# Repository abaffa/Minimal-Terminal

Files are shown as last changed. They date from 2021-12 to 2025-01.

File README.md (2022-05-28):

# Baffa Terminal (minimal-terminal clone) 

This is a Simple Terminal board based on "Minimal-Terminal" project by Carsten Herting (oct/2021 https://github.com/slu4coder/Minimal-Terminal).

Current version supports US-International keyboard mapping, four basic serial speeds (115200, 57600, 38400, 9600 BPS) and [supports some basic CSI/Ansi escapes](supported_escapes.md).
 
The prototype board has been tested with my CP/M machine (see http://baffa-2.baffasoft.com.br) but there is another board compatible with RC2014 pinout. 

### Video
minimal_terminal_video (http://www.youtube.com/watch?v=mmQTUNvmSpk "Baffa-2 Homebrew Microcomputer + Terminal Card")

## Baffa-2 Terminal Board:

[Order Baffa-2 Minimal Terminal PCB from PCBWay](https://www.pcbway.com/project/shareproject/Baffa_2_Minimal_Terminal_f85704c4.html)

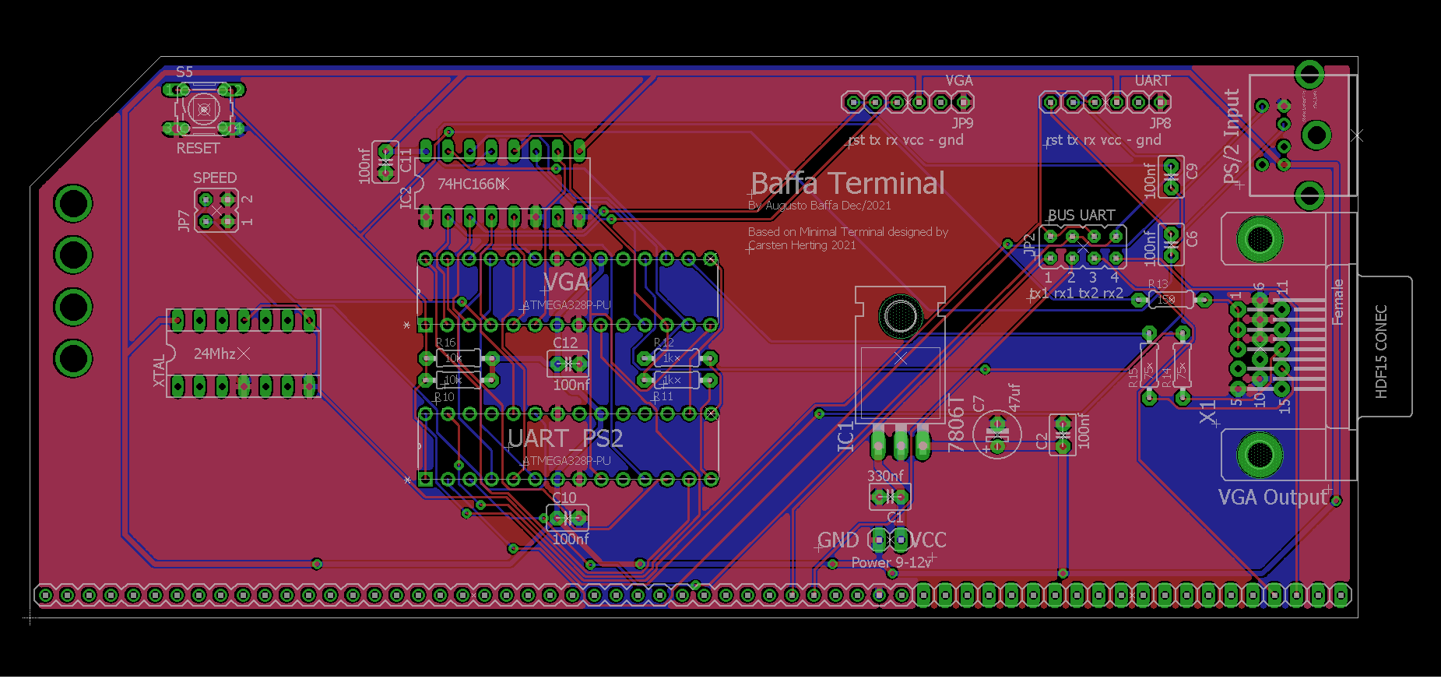
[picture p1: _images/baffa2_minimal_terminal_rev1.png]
minimal_terminalv2


## RC2014 Minimal-Terminal Module

[Order RC2014 Minimal Terminal PCB from PCBWay](https://www.pcbway.com/project/shareproject/RC2014_Minimal_Terminal_41593f8c.html)

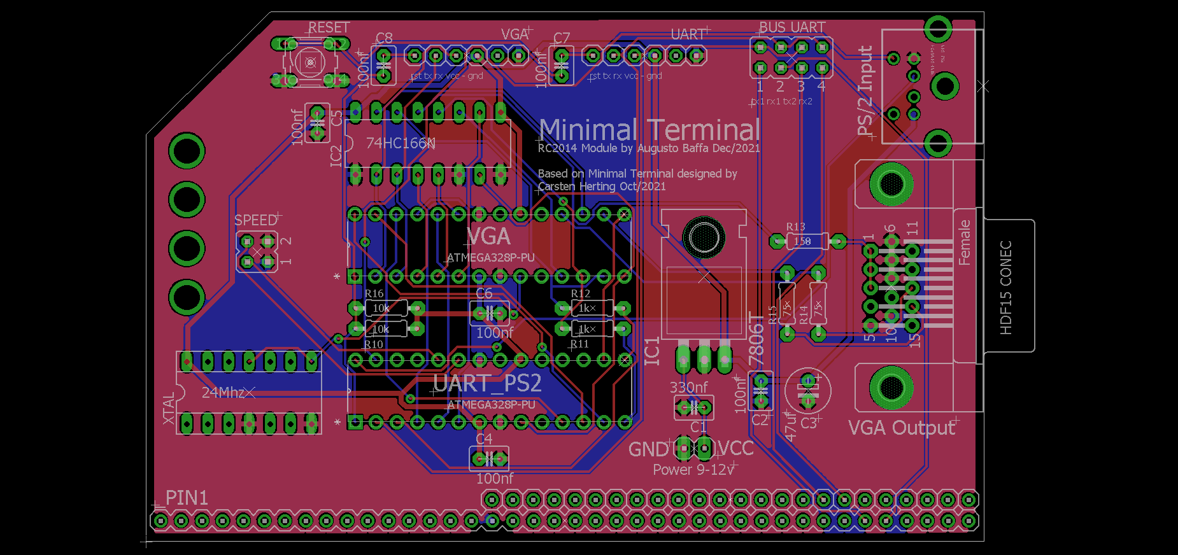
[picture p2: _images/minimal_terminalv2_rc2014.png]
minimal_terminalv2_rc2014


## Bill of Materials

| Qty | Value | Parts | Description |
|:---:|:---:|:-----|:-----|
| 1 |  PINHD-1X20 | JP4 |  PIN HEADER |
| 1 |  PINHD-1X40 | JP3 |  PIN HEADER |
| 6 |  100nf | C2, C6, C9, C10, C11, C12 | CAPACITOR |
| 2 |  10k | R10, R16 | RESISTOR |
| 1 | 150 | R13 | RESISTOR |
| 2 |  1k | R11, R12 | RESISTOR |
| 1 |  24Mhz XTAL |  XTAL |  XTAL SOCKET-14 |
| 1 |  330nf | C1 | CAPACITOR |
| 1 |  47uf | C7 | POLARIZED CAPACITOR |
| 1 |  74HC166N |  IC2 |  8-bit parallel load SHIFT REGISTER |
| 2 | 75 | R14, R15 | RESISTOR, American symbol |
| 1 |  7806T | IC1 |  Positive VOLTAGE REGULATOR |
| 2 |  ATMEGA328P-PU | UART_PS2, VGA |  PDIP-28 Atmel |
| 1 |  BUS UART | JP2 |  JUMPER |
| 1 |  MINI-DIN6PTH |  PS2_DIN |  mini DIN 6 Connector |
| 1 |  Power 9-12v | JP1 |  PIN HEADER |
| 1 |  RESET | S5 | MOM SWITCH |
| 1 |  SPEED | JP7 |  JUMPER |
| 1 | PINHD-1X6 | UART |  PIN HEADER |
| 1 | PINHD-1X6 |  VGA |  PIN HEADER |
| 1 | DSUB | VGA Output | SUB-D |
 
## License

Copyright (c) 2021 Augusto Baffa, Carsten Herting

Permission is hereby granted, free of charge, to any person obtaining a copy
of this software and associated documentation files (the "Software"), to deal
in the Software without restriction, including without limitation the rights
to use, copy, modify, merge, publish, distribute, sublicense, and/or sell
copies of the Software, and to permit persons to whom the Software is
furnished to do so, subject to the following conditions:

The above copyright notice and this permission notice shall be included in all
copies or substantial portions of the Software.

THE SOFTWARE IS PROVIDED "AS IS", WITHOUT WARRANTY OF ANY KIND, EXPRESS OR
IMPLIED, INCLUDING BUT NOT LIMITED TO THE WARRANTIES OF MERCHANTABILITY,
FITNESS FOR A PARTICULAR PURPOSE AND NONINFRINGEMENT. IN NO EVENT SHALL THE
AUTHORS OR COPYRIGHT HOLDERS BE LIABLE FOR ANY CLAIM, DAMAGES OR OTHER
LIABILITY, WHETHER IN AN ACTION OF CONTRACT, TORT OR OTHERWISE, ARISING FROM,
OUT OF OR IN CONNECTION WITH THE SOFTWARE OR THE USE OR OTHER DEALINGS IN THE
SOFTWARE.

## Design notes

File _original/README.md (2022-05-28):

## Original Minimal-Terminal Read.me

Minimal serial UART terminal with VGA and PS2 for up to 230400bps based upon ATmega328P.

This little gadget it ideally suited to be used together with the 'Minimal UART CPU System': https://github.com/slu4coder/Minimal-UART-CPU-System

See the manual section 'Native Tool Chain / Terminal' for more information:
https://docs.google.com/document/d/1c2ZHtLd1BBAwcBAjBZZJmCA3AXpbpv80dlAtsMYpuF4/edit?usp=sharing

---
MIT License

Copyright (c) 2021 Carsten Herting

Permission is hereby granted, free of charge, to any person obtaining a copy
of this software and associated documentation files (the "Software"), to deal
in the Software without restriction, including without limitation the rights
to use, copy, modify, merge, publish, distribute, sublicense, and/or sell
copies of the Software, and to permit persons to whom the Software is
furnished to do so, subject to the following conditions:

The above copyright notice and this permission notice shall be included in all
copies or substantial portions of the Software.

THE SOFTWARE IS PROVIDED "AS IS", WITHOUT WARRANTY OF ANY KIND, EXPRESS OR
IMPLIED, INCLUDING BUT NOT LIMITED TO THE WARRANTIES OF MERCHANTABILITY,
FITNESS FOR A PARTICULAR PURPOSE AND NONINFRINGEMENT. IN NO EVENT SHALL THE
AUTHORS OR COPYRIGHT HOLDERS BE LIABLE FOR ANY CLAIM, DAMAGES OR OTHER
LIABILITY, WHETHER IN AN ACTION OF CONTRACT, TORT OR OTHERWISE, ARISING FROM,
OUT OF OR IN CONNECTION WITH THE SOFTWARE OR THE USE OR OTHER DEALINGS IN THE
SOFTWARE.

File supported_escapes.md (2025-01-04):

# Minimal-Terminal / Supported Escape Sequences

Standard escape codes are prefixed with `Escape`:

- Ctrl-Key: `^[`
- Octal: `\033`
- Unicode: `\u001b`
- Hexadecimal: `\x1B`
- Decimal: `27`

- `CSI` - Control Sequence Introducer: sequence starting with `ESC [` or CSI (`\x9B`)

Followed by the command, somtimes delimited by opening square bracket (`[`), known as a Control Sequence Introducer (CSI), optionally followed by arguments and the command itself.

Arguments are delimeted by semi colon (`;`).

For example:

```sh
\x1b[1;31m  # Set style to bold, red foreground.
```
* Any whitespaces between sequences and arguments should be ignored. They are present for improved readability.

## Supported Cursor Controls

| ESC Code Sequence | Description |
| :--- | :--- |
| `ESC[H` | moves cursor to home position (0, 0) |
| `ESC[{line};{column}H` <br> `ESC[{line};{column}f` | moves cursor to line #, column # |
| `ESC[#A` | moves cursor up # lines |
| `ESC[#B` | moves cursor down # lines |
| `ESC[#C` | moves cursor right # columns |
| `ESC[#d` | moves cursor to an absolute # line |
| `ESC[#D` | moves cursor left # columns |
| `ESC[#E` | moves cursor to beginning of next line, # lines down |
| `ESC[#F` | moves cursor to beginning of previous line, # lines up |
| `ESC[#G` | moves cursor to column # |
| `ESC[#S` | scrolls down # lines |
| `ESC[#T` | scrolls up # lines |

## Supported Erase Functions

| ESC Code Sequence | Description |
| :--- | :--- |
| `ESC[J` | erase in display (same as ESC\[0J) |
| `ESC[0J` | erase from cursor until end of screen |
| `ESC[1J` | erase from cursor to beginning of screen  |
| `ESC[2J` | erase entire screen (set position:0,0) |
| `ESC[K` | erase in line (same as ESC\[0K) |
| `ESC[0K` | erase from cursor to end of line |
| `ESC[1K` | erase start of line to the cursor |
| `ESC[2K` | erase the entire line |

## Support Colors / Graphics Mode

| ESC Code Sequence | Reset Sequence | Description |
| :--- | :--- | :--- |
| `ESC[1;34;{...}m` | | Set graphics modes for cell, separated by semicolon (`;`). |
| `ESC[0m` | | reset all modes (styles and colors) |
| `ESC[7m` | `ESC[27m` | set inverse/reverse mode |

> **Note:** Colors are not supported and are ignored by terminal.

## References

- [Main Reference](https://gist.github.com/fnky/458719343aabd01cfb17a3a4f7296797)
- [Wikipedia: ANSI escape code](https://en.wikipedia.org/wiki/ANSI_escape_code)
- [Build your own Command Line with ANSI escape codes](http://www.lihaoyi.com/post/BuildyourownCommandLinewithANSIescapecodes.html)
- [ascii-table: ANSI Escape sequences](https://web.archive.org/web/20210226122732/http://ascii-table.com/ansi-escape-sequences.php)
- [bluesock: ansi codes](https://bluesock.org/~willkg/dev/ansi.html)
- [bash-hackers: Terminal Codes (ANSI/VT100) introduction](https://web.archive.org/web/20230405000510/https://wiki.bash-hackers.org/scripting/terminalcodes)
- [XTerm Control Sequences](https://invisible-island.net/xterm/ctlseqs/ctlseqs.html)
- [VT100 – Various terminal manuals](https://vt100.net/)
- [xterm.js – Supported Terminal Sequences](https://xtermjs.org/docs/api/vtfeatures/)
- [Microsoft Learn - Console virtual terminal sequences](https://learn.microsoft.com/pt-br/windows/console/console-virtual-terminal-sequences)

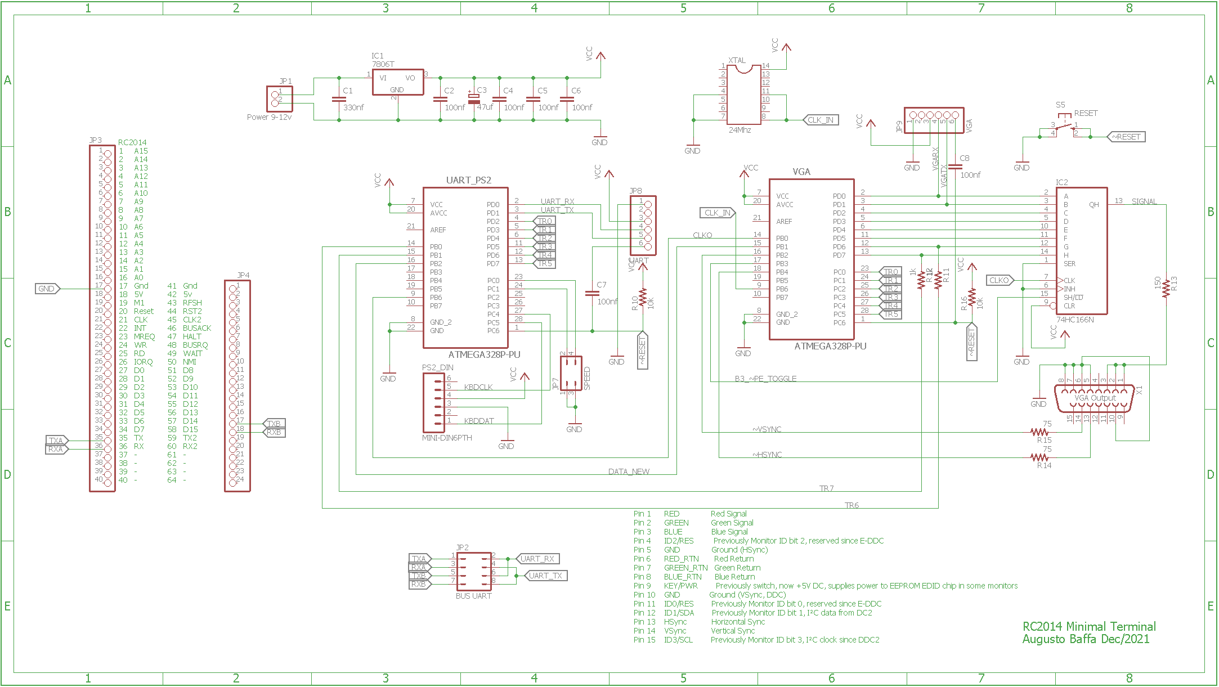
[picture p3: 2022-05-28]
schematics_rc2014_minimal_terminal.png

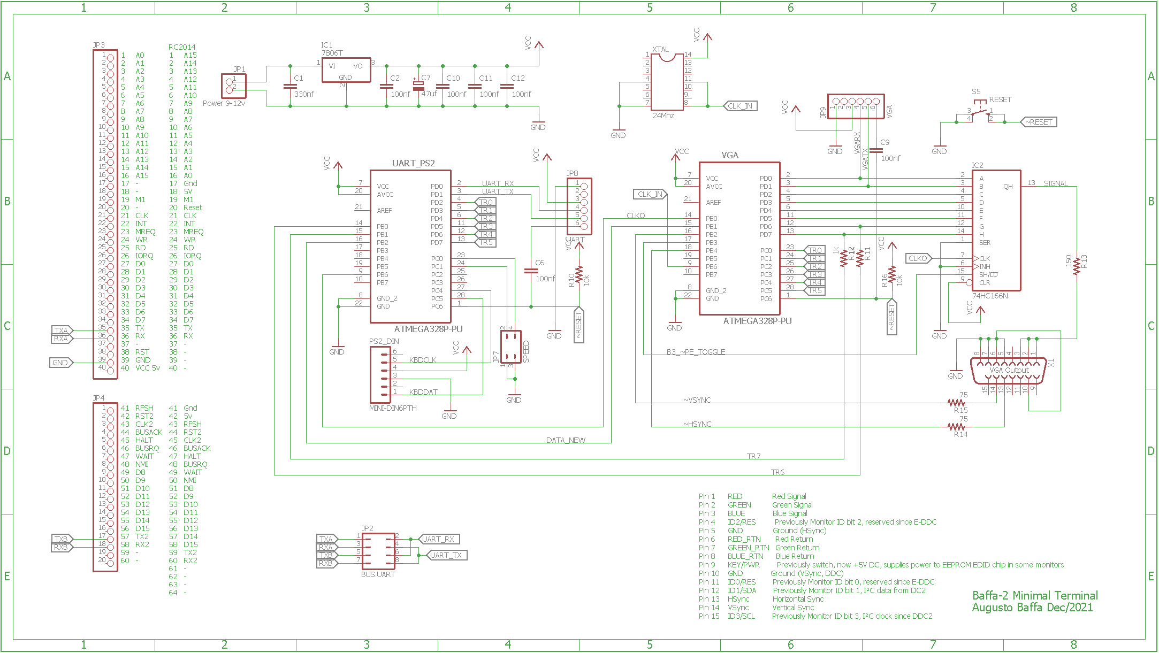
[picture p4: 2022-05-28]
schematics_baffa2_minimal_terminal.png

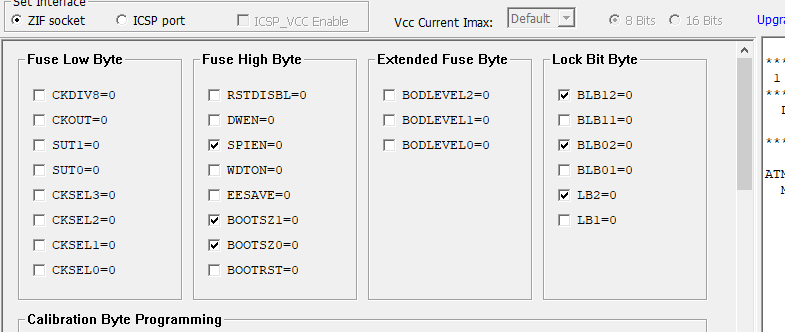
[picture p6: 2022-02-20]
Arduino_UART_Terminal_A_24MHz/fuse.png

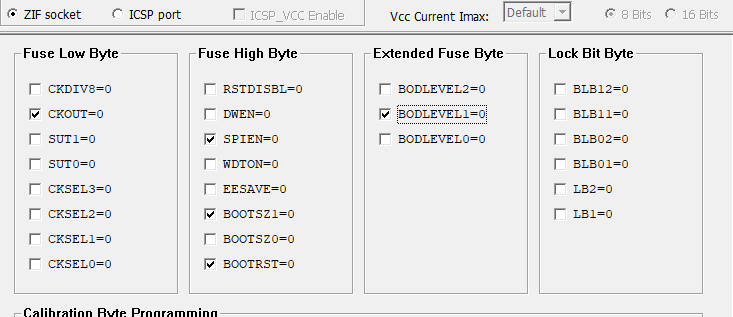
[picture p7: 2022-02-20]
Arduino_UART_Terminal_B_24MHz/fuse.png

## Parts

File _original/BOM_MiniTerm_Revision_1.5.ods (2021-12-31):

Item | Qty | Reference(s) | Value | LibPart | Footprint
1 | 2 | C1, C2 | .1µ | Device:C_Small | Capacitor_THT:C_Disc_D3.8mm_W2.6mm_P2.50mm
2 | 1 | C3 | 47µ | Device:CP | Capacitor_THT:CP_Radial_D6.3mm_P2.50mm
3 | 3 | C4, C9, C10 | .1µ | Device:C | Capacitor_THT:C_Disc_D3.8mm_W2.6mm_P2.50mm
4 | 2 | C5, C7 | 22p | Device:C_Small | Capacitor_THT:C_Disc_D5.0mm_W2.5mm_P2.50mm
5 | 1 | J1 | UART | Connector:Conn_01x06_Female | Connector_PinSocket_2.54mm:PinSocket_1x06_P2.54mm_Vertical
6 | 1 | J2 | PS/2 Keyboard | Connector:Mini-DIN-6 | ArduinoPC:FP_MINI_DIN_6_PS2
7 | 1 | J3 | VGA DB15 HD Connector (Female) | Connector:DB15_Female_HighDensity | ArduinoPC:VGA DSUB15HD_female
8 | 1 | J4 | 5V | Connector:Conn_01x02_Female | Connector_PinSocket_2.54mm:PinSocket_1x02_P2.54mm_Vertical
9 | 1 | J5 | VGA | Connector:Conn_01x06_Female | Connector_PinSocket_2.54mm:PinSocket_1x06_P2.54mm_Vertical
10 | 1 | J6 | SPEED | Connector_Generic:Conn_02x02_Top_Bottom | ArduinoPC:PinHeader_2x02_P2.54mm_Vertical_Jumper
11 | 2 | R1, R2 | 1k | Device:R | Resistor_THT:R_Axial_DIN0207_L6.3mm_D2.5mm_P7.62mm_Horizontal
12 | 2 | R3, R4 | 10k | Device:R | Resistor_THT:R_Axial_DIN0207_L6.3mm_D2.5mm_P7.62mm_Horizontal
13 | 1 | R5 | 150 | Device:R | Resistor_THT:R_Axial_DIN0207_L6.3mm_D2.5mm_P7.62mm_Horizontal
14 | 2 | R6, R7 | 75 | Device:R | Resistor_THT:R_Axial_DIN0207_L6.3mm_D2.5mm_P7.62mm_Horizontal
15 | 1 | SW1 | SW_Push | Switch:SW_Push | Button_Switch_THT:SW_PUSH_6mm
16 | 1 | U1 | 74HC166 | ArduinoPC:74HC166 | Package_DIP:DIP-16_W7.62mm
17 | 1 | U2 | ATmega328P (VGA) | ArduinoPC:ATmega328P-PU | Package_DIP:DIP-28_W7.62mm_Socket
18 | 1 | U3 | ATmega328P (UART & PS/2) | ArduinoPC:ATmega328P-PU | Package_DIP:DIP-28_W7.62mm_Socket
19 | 1 | Y1 | 24MHz | Device:Crystal_Small | Crystal:Crystal_HC18-U_Vertical
20 | 2 |  |  | Jumper

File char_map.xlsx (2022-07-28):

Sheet: Default Font
 | ASCII HEX | 0 | 1 | 2 | 3 | 4 | 5 | 6 | 7 | 8 | 9 | A | B | C | D | E | F | 10 | 11 | 12 | 13 | 14 | 15 | 16 | 17 | 18 | 19 | 1A | 1B | 1C | 1D | 1E | 1F | 20 | 21 | 22 | 23 | 24 | 25 | 26 | 27 | 28 | 29 | 2A | 2B | 2C | 2D | 2E | 2F | 30 | 31 | 32 | 33 | 34 | 35 | 36 | 37 | 38 | 39
Hex | 0x0 | 00 | 00 | 00 | 00 | 00 | 00 | 00 | 00 | 00 | 00 | 00 | 00 | 00 | 00 | 00 | 00 | 00 | 00 | 00 | 00 | 00 | 00 | 00 | 00 | 00 | 00 | 00 | 00 | 00 | 00 | 03 | C0 | 00 | 18 | 66 | 66 | 18 | 62 | 3C | 06 | 0C | 30 | 00 | 00 | 00 | 00 | 00 | 00 | 3C | 18 | 3C | 3C | 06 | 7E | 3C | 7E | 3C | 3C
 | 0x1 | 00 | 00 | 00 | 00 | 00 | 00 | 00 | 00 | 00 | 00 | 00 | 00 | 00 | 00 | 00 | 00 | 00 | 00 | 00 | 00 | 00 | 00 | 00 | 00 | 00 | 00 | 00 | 00 | 00 | 00 | 07 | E0 | 00 | 18 | 66 | 66 | 3E | 66 | 66 | 0C | 18 | 18 | 66 | 18 | 00 | 00 | 00 | 03 | 66 | 18 | 66 | 66 | 0E | 60 | 66 | 66 | 66 | 66
 | 0x2 | 00 | 00 | 00 | 00 | 00 | 00 | 00 | 00 | 00 | 00 | 00 | 00 | 00 | 00 | 00 | 00 | 00 | 00 | 00 | 00 | 00 | 00 | 00 | 00 | 00 | 00 | 00 | 00 | 00 | 00 | 0E | 70 | 00 | 18 | 66 | FF | 60 | 0C | 3C | 18 | 30 | 0C | 3C | 18 | 00 | 00 | 00 | 06 | 6E | 38 | 06 | 06 | 1E | 7C | 60 | 0C | 66 | 66
 | 0x3 | 00 | 00 | 00 | 00 | 00 | 00 | 00 | 00 | 00 | 00 | 00 | 00 | 00 | 00 | 00 | 00 | 00 | 00 | 00 | 00 | 00 | 00 | 00 | 00 | 00 | 00 | 00 | 00 | 00 | 00 | 1C | 38 | 00 | 18 | 00 | 66 | 3C | 18 | 38 | 00 | 30 | 0C | FF | 7E | 00 | 7E | 00 | 0C | 76 | 18 | 0C | 1C | 66 | 06 | 7C | 18 | 3C | 3E
 | 0x4 | 00 | 00 | 00 | 00 | 00 | 00 | 00 | 00 | 00 | 00 | 00 | 00 | 00 | 00 | 00 | 00 | 00 | 00 | 00 | 00 | 00 | 00 | 00 | 00 | 00 | 00 | 00 | 00 | 00 | 00 | 38 | 1C | 00 | 00 | 00 | FF | 06 | 30 | 67 | 00 | 30 | 0C | 3C | 18 | 00 | 00 | 00 | 18 | 66 | 18 | 30 | 06 | 7F | 06 | 66 | 18 | 66 | 06
 | 0x5 | 00 | 00 | 00 | 00 | 00 | 00 | 00 | 00 | 00 | 00 | 00 | 00 | 00 | 00 | 00 | 00 | 00 | 00 | 00 | 00 | 00 | 00 | 00 | 00 | 00 | 00 | 00 | 00 | 00 | 00 | 70 | 0E | 00 | 00 | 00 | 66 | 7C | 66 | 66 | 00 | 18 | 18 | 66 | 18 | 18 | 00 | 18 | 30 | 66 | 18 | 60 | 66 | 06 | 66 | 66 | 18 | 66 | 66
 | 0x6 | 00 | 00 | 00 | 00 | 00 | 00 | 00 | 00 | 00 | 00 | 00 | 00 | 00 | 00 | 00 | 00 | 00 | 00 | 00 | 00 | 00 | 00 | 00 | 00 | 00 | 00 | 00 | 00 | 00 | 00 | E0 | 07 | 00 | 18 | 00 | 66 | 18 | 46 | 3F | 00 | 0C | 30 | 00 | 00 | 18 | 00 | 18 | 60 | 3C | 7E | 7E | 3C | 06 | 3C | 3C | 18 | 3C | 3C
 | 0x7 | 00 | 00 | 00 | 00 | 00 | 00 | 00 | 00 | 00 | 00 | 00 | 00 | 00 | 00 | 00 | 00 | 00 | 00 | 00 | 00 | 00 | 00 | 00 | 00 | 00 | 00 | 00 | 00 | 00 | 00 | C0 | 03 | 00 | 00 | 00 | 00 | 00 | 00 | 00 | 00 | 00 | 00 | 00 | 00 | 30 | 00 | 00 | 00 | 00 | 00 | 00 | 00 | 00 | 00 | 00 | 00 | 00 | 00
Bitmap | 0b0 | ........ | ........ | ........ | ........ | ........ | ........ | ........ | ........ | ........ | ........ | ........ | ........ | ........ | ........ | ........ | ........ | ........ | ........ | ........ | ........ | ........ | ........ | ........ | ........ | ........ | ........ | ........ | ........ | ........ | ........ | ......██ | ██...... | ........ | ...██... | .██..██. | .██..██. | ...██... | .██...█. | ..████.. | .....██. | ....██.. | ..██.... | ........ | ........ | ........ | ........ | ........ | ........ | ..████.. | ...██... | ..████.. | ..████.. | .....██. | .██████. | ..████.. | .██████. | ..████.. | ..████..
 | 0b1 | ........ | ........ | ........ | ........ | ........ | ........ | ........ | ........ | ........ | ........ | ........ | ........ | ........ | ........ | ........ | ........ | ........ | ........ | ........ | ........ | ........ | ........ | ........ | ........ | ........ | ........ | ........ | ........ | ........ | ........ | .....███ | ███..... | ........ | ...██... | .██..██. | .██..██. | ..█████. | .██..██. | .██..██. | ....██.. | ...██... | ...██... | .██..██. | ...██... | ........ | ........ | ........ | ......██ | .██..██. | ...██... | .██..██. | .██..██. | ....███. | .██..... | .██..██. | .██..██. | .██..██. | .██..██.
 | 0b2 | ........ | ........ | ........ | ........ | ........ | ........ | ........ | ........ | ........ | ........ | ........ | ........ | ........ | ........ | ........ | ........ | ........ | ........ | ........ | ........ | ........ | ........ | ........ | ........ | ........ | ........ | ........ | ........ | ........ | ........ | ....███. | .███.... | ........ | ...██... | .██..██. | ████████ | .██..... | ....██.. | ..████.. | ...██... | ..██.... | ....██.. | ..████.. | ...██... | ........ | ........ | ........ | .....██. | .██.███. | ..███... | .....██. | .....██. | ...████. | .█████.. | .██..... | ....██.. | .██..██. | .██..██.
 | 0b3 | ........ | ........ | ........ | ........ | ........ | ........ | ........ | ........ | ........ | ........ | ........ | ........ | ........ | ........ | ........ | ........ | ........ | ........ | ........ | ........ | ........ | ........ | ........ | ........ | ........ | ........ | ........ | ........ | ........ | ........ | ...███.. | ..███... | ........ | ...██... | ........ | .██..██. | ..████.. | ...██... | ..███... | ........ | ..██.... | ....██.. | ████████ | .██████. | ........ | .██████. | ........ | ....██.. | .███.██. | ...██... | ....██.. | ...███.. | .██..██. | .....██. | .█████.. | ...██... | ..████.. | ..█████.
 | 0b4 | ........ | ........ | ........ | ........ | ........ | ........ | ........ | ........ | ........ | ........ | ........ | ........ | ........ | ........ | ........ | ........ | ........ | ........ | ........ | ........ | ........ | ........ | ........ | ........ | ........ | ........ | ........ | ........ | ........ | ........ | ..███... | ...███.. | ........ | ........ | ........ | ████████ | .....██. | ..██.... | .██..███ | ........ | ..██.... | ....██.. | ..████.. | ...██... | ........ | ........ | ........ | ...██... | .██..██. | ...██... | ..██.... | .....██. | .███████ | .....██. | .██..██. | ...██... | .██..██. | .....██.
 | 0b5 | ........ | ........ | ........ | ........ | ........ | ........ | ........ | ........ | ........ | ........ | ........ | ........ | ........ | ........ | ........ | ........ | ........ | ........ | ........ | ........ | ........ | ........ | ........ | ........ | ........ | ........ | ........ | ........ | ........ | ........ | .███.... | ....███. | ........ | ........ | ........ | .██..██. | .█████.. | .██..██. | .██..██. | ........ | ...██... | ...██... | .██..██. | ...██... | ...██... | ........ | ...██... | ..██.... | .██..██. | ...██... | .██..... | .██..██. | .....██. | .██..██. | .██..██. | ...██... | .██..██. | .██..██.
 | 0b6 | ........ | ........ | ........ | ........ | ........ | ........ | ........ | ........ | ........ | ........ | ........ | ........ | ........ | ........ | ........ | ........ | ........ | ........ | ........ | ........ | ........ | ........ | ........ | ........ | ........ | ........ | ........ | ........ | ........ | ........ | ███..... | .....███ | ........ | ...██... | ........ | .██..██. | ...██... | .█...██. | ..██████ | ........ | ....██.. | ..██.... | ........ | ........ | ...██... | ........ | ...██... | .██..... | ..████.. | .██████. | .██████. | ..████.. | .....██. | ..████.. | ..████.. | ...██... | ..████.. | ..████..
 | 0b7 | ........ | ........ | ........ | ........ | ........ | ........ | ........ | ........ | ........ | ........ | ........ | ........ | ........ | ........ | ........ | ........ | ........ | ........ | ........ | ........ | ........ | ........ | ........ | ........ | ........ | ........ | ........ | ........ | ........ | ........ | ██...... | ......██ | ........ | ........ | ........ | ........ | ........ | ........ | ........ | ........ | ........ | ........ | ........ | ........ | ..██.... | ........ | ........ | ........ | ........ | ........ | ........ | ........ | ........ | ........ | ........ | ........ | ........ | ........
 | ASCII DEC | 0 | 1 | 2 | 3 | 4 | 5 | 6 | 7 | 8 | 9 | 10 | 11 | 12 | 13 | 14 | 15 | 16 | 17 | 18 | 19 | 20 | 21 | 22 | 23 | 24 | 25 | 26 | 27 | 28 | 29 | 30 | 31 | 32 | 33 | 34 | 35 | 36 | 37 | 38 | 39 | 40 | 41 | 42 | 43 | 44 | 45 | 46 | 47 | 48 | 49 | 50 | 51 | 52 | 53 | 54 | 55 | 56 | 57
 | Char | #VALUE! | _x0001_ | _x0002_ | _x0003_ | _x0004_ | _x0005_ | _x0006_ | _x0007_ | _x0008_ |  |  | _x000B_ | _x000C_ | _x000D_ | _x000E_ | _x000F_ | _x0010_ | _x0011_ | _x0012_ | _x0013_ | _x0014_ | _x0015_ | _x0016_ | _x0017_ | _x0018_ | _x0019_ | _x001A_ | _x001B_ | _x001C_ | _x001D_ | _x001E_ | _x001F_ |  | ! | " | # | $ | % | & | ' | ( | ) | * | + | , | - | . | / | 0 | 1 | 2 | 3 | 4 | 5 | 6 | 7 | 8 | 9

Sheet: Apple1
 | ASCII HEX | 0 | 1 | 2 | 3 | 4 | 5 | 6 | 7 | 8 | 9 | A | B | C | D | E | F | 10 | 11 | 12 | 13 | 14 | 15 | 16 | 17 | 18 | 19 | 1A | 1B | 1C | 1D | 1E | 1F | 20 | 21 | 22 | 23 | 24 | 25 | 26 | 27 | 28 | 29 | 2A | 2B | 2C | 2D | 2E | 2F | 30 | 31 | 32 | 33 | 34 | 35 | 36 | 37 | 38 | 39
Hex | 0x0 | 00 | 00 | 00 | 00 | 00 | 00 | 00 | 00 | 00 | 00 | 00 | 00 | 00 | 00 | 00 | 00 | 00 | 00 | 00 | 00 | 00 | 00 | 00 | 00 | 00 | 00 | 00 | 00 | 00 | 00 | 00 | 00 | 00 | 00 | 00 | 00 | 00 | 00 | 00 | 00 | 00 | 00 | 00 | 00 | 00 | 00 | 00 | 00 | 00 | 00 | 00 | 00 | 00 | 00 | 00 | 00 | 00 | 00
 | 0x1 | 0e | 04 | 1e | 0e | 1e | 1f | 1f | 0f | 11 | 0e | 01 | 11 | 10 | 11 | 11 | 0e | 1e | 0e | 1e | 0e | 1f | 11 | 11 | 11 | 11 | 11 | 1f | 1f | 00 | 1f | 00 | 00 | 00 | 04 | 0a | 0a | 04 | 18 | 08 | 04 | 04 | 04 | 04 | 00 | 00 | 00 | 00 | 00 | 0e | 04 | 0e | 1f | 02 | 1f | 07 | 1f | 0e | 0e
 | 0x2 | 11 | 0a | 11 | 11 | 11 | 10 | 10 | 10 | 11 | 04 | 01 | 12 | 10 | 1b | 11 | 11 | 11 | 11 | 11 | 11 | 04 | 11 | 11 | 11 | 11 | 11 | 01 | 18 | 10 | 03 | 00 | 00 | 00 | 04 | 0a | 0a | 0f | 19 | 14 | 04 | 08 | 02 | 15 | 04 | 00 | 00 | 00 | 01 | 11 | 0c | 11 | 01 | 06 | 10 | 08 | 01 | 11 | 11
 | 0x3 | 15 | 11 | 11 | 10 | 11 | 10 | 10 | 10 | 11 | 04 | 01 | 14 | 10 | 15 | 19 | 11 | 11 | 11 | 11 | 10 | 04 | 11 | 11 | 11 | 0a | 0a | 02 | 18 | 08 | 03 | 04 | 00 | 00 | 04 | 0a | 1f | 14 | 02 | 14 | 04 | 10 | 01 | 0e | 04 | 00 | 00 | 00 | 02 | 13 | 04 | 01 | 02 | 0a | 1e | 10 | 02 | 11 | 11
 | 0x4 | 17 | 11 | 1e | 10 | 11 | 1e | 1e | 10 | 1f | 04 | 01 | 18 | 10 | 15 | 15 | 11 | 1e | 11 | 1e | 0e | 04 | 11 | 11 | 15 | 04 | 04 | 04 | 18 | 04 | 03 | 0a | 00 | 00 | 04 | 00 | 0a | 0e | 04 | 08 | 00 | 10 | 01 | 04 | 1f | 00 | 1f | 00 | 04 | 15 | 04 | 06 | 06 | 12 | 01 | 1e | 04 | 0e | 0f
 | 0x5 | 16 | 1f | 11 | 10 | 11 | 10 | 10 | 13 | 11 | 04 | 01 | 14 | 10 | 11 | 13 | 11 | 10 | 15 | 14 | 01 | 04 | 11 | 11 | 15 | 0a | 04 | 08 | 18 | 02 | 03 | 11 | 00 | 00 | 04 | 00 | 1f | 05 | 08 | 15 | 00 | 10 | 01 | 0e | 04 | 04 | 00 | 00 | 08 | 19 | 04 | 08 | 01 | 1f | 01 | 11 | 08 | 11 | 01
 | 0x6 | 10 | 11 | 11 | 11 | 11 | 10 | 10 | 11 | 11 | 04 | 11 | 12 | 10 | 11 | 11 | 11 | 10 | 12 | 12 | 11 | 04 | 11 | 0a | 1b | 11 | 04 | 10 | 18 | 01 | 03 | 00 | 00 | 00 | 00 | 00 | 0a | 1e | 13 | 12 | 00 | 08 | 02 | 15 | 04 | 04 | 00 | 00 | 10 | 11 | 04 | 10 | 11 | 02 | 11 | 11 | 08 | 11 | 02
 | 0x7 | 0f | 11 | 1e | 0e | 1e | 1f | 10 | 0f | 11 | 0e | 0e | 11 | 1f | 11 | 11 | 0e | 10 | 0d | 11 | 0e | 04 | 0e | 04 | 11 | 11 | 04 | 1f | 1f | 00 | 1f | 00 | 1f | 00 | 04 | 00 | 0a | 04 | 03 | 0d | 00 | 04 | 04 | 04 | 00 | 08 | 00 | 04 | 00 | 0e | 0e | 1f | 0e | 02 | 0e | 0e | 08 | 0e | 1c
Bitmap | 0b0 | ........ | ........ | ........ | ........ | ........ | ........ | ........ | ........ | ........ | ........ | ........ | ........ | ........ | ........ | ........ | ........ | ........ | ........ | ........ | ........ | ........ | ........ | ........ | ........ | ........ | ........ | ........ | ........ | ........ | ........ | ........ | ........ | ........ | ........ | ........ | ........ | ........ | ........ | ........ | ........ | ........ | ........ | ........ | ........ | ........ | ........ | ........ | ........ | ........ | ........ | ........ | ........ | ........ | ........ | ........ | ........ | ........ | ........
 | 0b1 | ....███. | .....█.. | ...████. | ....███. | ...████. | ...█████ | ...█████ | ....████ | ...█...█ | ....███. | .......█ | ...█...█ | ...█.... | ...█...█ | ...█...█ | ....███. | ...████. | ....███. | ...████. | ....███. | ...█████ | ...█...█ | ...█...█ | ...█...█ | ...█...█ | ...█...█ | ...█████ | ...█████ | ........ | ...█████ | ........ | ........ | ........ | .....█.. | ....█.█. | ....█.█. | .....█.. | ...██... | ....█... | .....█.. | .....█.. | .....█.. | .....█.. | ........ | ........ | ........ | ........ | ........ | ....███. | .....█.. | ....███. | ...█████ | ......█. | ...█████ | .....███ | ...█████ | ....███. | ....███.
 | 0b2 | ...█...█ | ....█.█. | ...█...█ | ...█...█ | ...█...█ | ...█.... | ...█.... | ...█.... | ...█...█ | .....█.. | .......█ | ...█..█. | ...█.... | ...██.██ | ...█...█ | ...█...█ | ...█...█ | ...█...█ | ...█...█ | ...█...█ | .....█.. | ...█...█ | ...█...█ | ...█...█ | ...█...█ | ...█...█ | .......█ | ...██... | ...█.... | ......██ | ........ | ........ | ........ | .....█.. | ....█.█. | ....█.█. | ....████ | ...██..█ | ...█.█.. | .....█.. | ....█... | ......█. | ...█.█.█ | .....█.. | ........ | ........ | ........ | .......█ | ...█...█ | ....██.. | ...█...█ | .......█ | .....██. | ...█.... | ....█... | .......█ | ...█...█ | ...█...█
 | 0b3 | ...█.█.█ | ...█...█ | ...█...█ | ...█.... | ...█...█ | ...█.... | ...█.... | ...█.... | ...█...█ | .....█.. | .......█ | ...█.█.. | ...█.... | ...█.█.█ | ...██..█ | ...█...█ | ...█...█ | ...█...█ | ...█...█ | ...█.... | .....█.. | ...█...█ | ...█...█ | ...█...█ | ....█.█. | ....█.█. | ......█. | ...██... | ....█... | ......██ | .....█.. | ........ | ........ | .....█.. | ....█.█. | ...█████ | ...█.█.. | ......█. | ...█.█.. | .....█.. | ...█.... | .......█ | ....███. | .....█.. | ........ | ........ | ........ | ......█. | ...█..██ | .....█.. | .......█ | ......█. | ....█.█. | ...████. | ...█.... | ......█. | ...█...█ | ...█...█
 | 0b4 | ...█.███ | ...█...█ | ...████. | ...█.... | ...█...█ | ...████. | ...████. | ...█.... | ...█████ | .....█.. | .......█ | ...██... | ...█.... | ...█.█.█ | ...█.█.█ | ...█...█ | ...████. | ...█...█ | ...████. | ....███. | .....█.. | ...█...█ | ...█...█ | ...█.█.█ | .....█.. | .....█.. | .....█.. | ...██... | .....█.. | ......██ | ....█.█. | ........ | ........ | .....█.. | ........ | ....█.█. | ....███. | .....█.. | ....█... | ........ | ...█.... | .......█ | .....█.. | ...█████ | ........ | ...█████ | ........ | .....█.. | ...█.█.█ | .....█.. | .....██. | .....██. | ...█..█. | .......█ | ...████. | .....█.. | ....███. | ....████
 | 0b5 | ...█.██. | ...█████ | ...█...█ | ...█.... | ...█...█ | ...█.... | ...█.... | ...█..██ | ...█...█ | .....█.. | .......█ | ...█.█.. | ...█.... | ...█...█ | ...█..██ | ...█...█ | ...█.... | ...█.█.█ | ...█.█.. | .......█ | .....█.. | ...█...█ | ...█...█ | ...█.█.█ | ....█.█. | .....█.. | ....█... | ...██... | ......█. | ......██ | ...█...█ | ........ | ........ | .....█.. | ........ | ...█████ | .....█.█ | ....█... | ...█.█.█ | ........ | ...█.... | .......█ | ....███. | .....█.. | .....█.. | ........ | ........ | ....█... | ...██..█ | .....█.. | ....█... | .......█ | ...█████ | .......█ | ...█...█ | ....█... | ...█...█ | .......█
 | 0b6 | ...█.... | ...█...█ | ...█...█ | ...█...█ | ...█...█ | ...█.... | ...█.... | ...█...█ | ...█...█ | .....█.. | ...█...█ | ...█..█. | ...█.... | ...█...█ | ...█...█ | ...█...█ | ...█.... | ...█..█. | ...█..█. | ...█...█ | .....█.. | ...█...█ | ....█.█. | ...██.██ | ...█...█ | .....█.. | ...█.... | ...██... | .......█ | ......██ | ........ | ........ | ........ | ........ | ........ | ....█.█. | ...████. | ...█..██ | ...█..█. | ........ | ....█... | ......█. | ...█.█.█ | .....█.. | .....█.. | ........ | ........ | ...█.... | ...█...█ | .....█.. | ...█.... | ...█...█ | ......█. | ...█...█ | ...█...█ | ....█... | ...█...█ | ......█.
 | 0b7 | ....████ | ...█...█ | ...████. | ....███. | ...████. | ...█████ | ...█.... | ....████ | ...█...█ | ....███. | ....███. | ...█...█ | ...█████ | ...█...█ | ...█...█ | ....███. | ...█.... | ....██.█ | ...█...█ | ....███. | .....█.. | ....███. | .....█.. | ...█...█ | ...█...█ | .....█.. | ...█████ | ...█████ | ........ | ...█████ | ........ | ...█████ | ........ | .....█.. | ........ | ....█.█. | .....█.. | ......██ | ....██.█ | ........ | .....█.. | .....█.. | .....█.. | ........ | ....█... | ........ | .....█.. | ........ | ....███. | ....███. | ...█████ | ....███. | ......█. | ....███. | ....███. | ....█... | ....███. | ...███..
 | ASCII DEC | 0 | 1 | 2 | 3 | 4 | 5 | 6 | 7 | 8 | 9 | 10 | 11 | 12 | 13 | 14 | 15 | 16 | 17 | 18 | 19 | 20 | 21 | 22 | 23 | 24 | 25 | 26 | 27 | 28 | 29 | 30 | 31 | 32 | 33 | 34 | 35 | 36 | 37 | 38 | 39 | 40 | 41 | 42 | 43 | 44 | 45 | 46 | 47 | 48 | 49 | 50 | 51 | 52 | 53 | 54 | 55 | 56 | 57
 | Char | #VALUE! | _x0001_ | _x0002_ | _x0003_ | _x0004_ | _x0005_ | _x0006_ | _x0007_ | _x0008_ |  |  | _x000B_ | _x000C_ | _x000D_ | _x000E_ | _x000F_ | _x0010_ | _x0011_ | _x0012_ | _x0013_ | _x0014_ | _x0015_ | _x0016_ | _x0017_ | _x0018_ | _x0019_ | _x001A_ | _x001B_ | _x001C_ | _x001D_ | _x001E_ | _x001F_ |  | ! | " | # | $ | % | & | ' | ( | ) | * | + | , | - | . | / | 0 | 1 | 2 | 3 | 4 | 5 | 6 | 7 | 8 | 9

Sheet: Apple2ExatoPro
 | ASCII HEX | 0 | 1 | 2 | 3 | 4 | 5 | 6 | 7 | 8 | 9 | A | B | C | D | E | F | 10 | 11 | 12 | 13 | 14 | 15 | 16 | 17 | 18 | 19 | 1A | 1B | 1C | 1D | 1E | 1F | 20 | 21 | 22 | 23 | 24 | 25 | 26 | 27 | 28 | 29 | 2A | 2B | 2C | 2D | 2E | 2F | 30 | 31 | 32 | 33 | 34 | 35 | 36 | 37 | 38 | 39
Hex | 0x0 | 1c | 08 | 3c | 1c | 3c | 3e | 3e | 1e | 22 | 1c | 02 | 22 | 20 | 22 | 22 | 1c | 3c | 1c | 3c | 1c | 3e | 22 | 22 | 22 | 22 | 22 | 3e | 3e | 00 | 3e | 00 | 00 | 00 | 08 | 14 | 14 | 08 | 30 | 10 | 08 | 08 | 08 | 08 | 00 | 00 | 00 | 00 | 00 | 1c | 08 | 1c | 3e | 04 | 3e | 0e | 3e | 1c | 1c
 | 0x1 | 22 | 14 | 22 | 22 | 22 | 20 | 20 | 20 | 22 | 08 | 02 | 24 | 20 | 36 | 22 | 22 | 22 | 22 | 22 | 22 | 08 | 22 | 22 | 22 | 22 | 22 | 02 | 30 | 20 | 06 | 00 | 00 | 00 | 08 | 14 | 14 | 1e | 32 | 28 | 08 | 10 | 04 | 2a | 08 | 00 | 00 | 00 | 02 | 22 | 18 | 22 | 02 | 0c | 20 | 10 | 02 | 22 | 22
 | 0x2 | 2a | 22 | 22 | 20 | 22 | 20 | 20 | 20 | 22 | 08 | 02 | 28 | 20 | 2a | 32 | 22 | 22 | 22 | 22 | 20 | 08 | 22 | 22 | 22 | 14 | 14 | 04 | 30 | 10 | 06 | 08 | 00 | 00 | 08 | 14 | 3e | 28 | 04 | 28 | 10 | 20 | 02 | 1c | 08 | 00 | 00 | 00 | 04 | 26 | 08 | 02 | 04 | 14 | 3c | 20 | 04 | 22 | 22
 | 0x3 | 2e | 22 | 3c | 20 | 22 | 3c | 3c | 20 | 3e | 08 | 02 | 30 | 20 | 2a | 2a | 22 | 3c | 22 | 3c | 1c | 08 | 22 | 22 | 2a | 08 | 08 | 08 | 30 | 08 | 06 | 14 | 00 | 00 | 08 | 00 | 14 | 1c | 08 | 10 | 00 | 20 | 02 | 08 | 3e | 00 | 3e | 00 | 08 | 2a | 08 | 0c | 0c | 24 | 02 | 3c | 08 | 1c | 1e
 | 0x4 | 2c | 3e | 22 | 20 | 22 | 20 | 20 | 26 | 22 | 08 | 02 | 28 | 20 | 22 | 26 | 22 | 20 | 2a | 28 | 02 | 08 | 22 | 22 | 2a | 14 | 08 | 10 | 30 | 04 | 06 | 22 | 00 | 00 | 08 | 00 | 3e | 0a | 10 | 2a | 00 | 20 | 02 | 1c | 08 | 08 | 00 | 00 | 10 | 32 | 08 | 10 | 02 | 3e | 02 | 22 | 10 | 22 | 02
 | 0x5 | 20 | 22 | 22 | 22 | 22 | 20 | 20 | 22 | 22 | 08 | 22 | 24 | 20 | 22 | 22 | 22 | 20 | 24 | 24 | 22 | 08 | 22 | 14 | 36 | 22 | 08 | 20 | 30 | 02 | 06 | 00 | 00 | 00 | 00 | 00 | 14 | 3c | 26 | 24 | 00 | 10 | 04 | 2a | 08 | 08 | 00 | 00 | 20 | 22 | 08 | 20 | 22 | 04 | 22 | 22 | 10 | 22 | 04
 | 0x6 | 1e | 22 | 3c | 1c | 3c | 3e | 20 | 1e | 22 | 1c | 1c | 22 | 3e | 22 | 22 | 1c | 20 | 1a | 22 | 1c | 08 | 1c | 08 | 22 | 22 | 08 | 3e | 3e | 00 | 3e | 00 | 00 | 00 | 08 | 00 | 14 | 08 | 06 | 1a | 00 | 08 | 08 | 08 | 00 | 10 | 00 | 08 | 00 | 1c | 1c | 3e | 1c | 04 | 1c | 1c | 10 | 1c | 38
 | 0x7 | 00 | 00 | 00 | 00 | 00 | 00 | 00 | 00 | 00 | 00 | 00 | 00 | 00 | 00 | 00 | 00 | 00 | 00 | 00 | 00 | 00 | 00 | 00 | 00 | 00 | 00 | 00 | 00 | 00 | 00 | 00 | 3f | 00 | 00 | 00 | 00 | 00 | 00 | 00 | 00 | 00 | 00 | 00 | 00 | 00 | 00 | 00 | 00 | 00 | 00 | 00 | 00 | 00 | 00 | 00 | 00 | 00 | 00
Bitmap | 0b0 | ...███.. | ....█... | ..████.. | ...███.. | ..████.. | ..█████. | ..█████. | ...████. | ..█...█. | ...███.. | ......█. | ..█...█. | ..█..... | ..█...█. | ..█...█. | ...███.. | ..████.. | ...███.. | ..████.. | ...███.. | ..█████. | ..█...█. | ..█...█. | ..█...█. | ..█...█. | ..█...█. | ..█████. | ..█████. | ........ | ..█████. | ........ | ........ | ........ | ....█... | ...█.█.. | ...█.█.. | ....█... | ..██.... | ...█.... | ....█... | ....█... | ....█... | ....█... | ........ | ........ | ........ | ........ | ........ | ...███.. | ....█... | ...███.. | ..█████. | .....█.. | ..█████. | ....███. | ..█████. | ...███.. | ...███..
 | 0b1 | ..█...█. | ...█.█.. | ..█...█. | ..█...█. | ..█...█. | ..█..... | ..█..... | ..█..... | ..█...█. | ....█... | ......█. | ..█..█.. | ..█..... | ..██.██. | ..█...█. | ..█...█. | ..█...█. | ..█...█. | ..█...█. | ..█...█. | ....█... | ..█...█. | ..█...█. | ..█...█. | ..█...█. | ..█...█. | ......█. | ..██.... | ..█..... | .....██. | ........ | ........ | ........ | ....█... | ...█.█.. | ...█.█.. | ...████. | ..██..█. | ..█.█... | ....█... | ...█.... | .....█.. | ..█.█.█. | ....█... | ........ | ........ | ........ | ......█. | ..█...█. | ...██... | ..█...█. | ......█. | ....██.. | ..█..... | ...█.... | ......█. | ..█...█. | ..█...█.
 | 0b2 | ..█.█.█. | ..█...█. | ..█...█. | ..█..... | ..█...█. | ..█..... | ..█..... | ..█..... | ..█...█. | ....█... | ......█. | ..█.█... | ..█..... | ..█.█.█. | ..██..█. | ..█...█. | ..█...█. | ..█...█. | ..█...█. | ..█..... | ....█... | ..█...█. | ..█...█. | ..█...█. | ...█.█.. | ...█.█.. | .....█.. | ..██.... | ...█.... | .....██. | ....█... | ........ | ........ | ....█... | ...█.█.. | ..█████. | ..█.█... | .....█.. | ..█.█... | ...█.... | ..█..... | ......█. | ...███.. | ....█... | ........ | ........ | ........ | .....█.. | ..█..██. | ....█... | ......█. | .....█.. | ...█.█.. | ..████.. | ..█..... | .....█.. | ..█...█. | ..█...█.
 | 0b3 | ..█.███. | ..█...█. | ..████.. | ..█..... | ..█...█. | ..████.. | ..████.. | ..█..... | ..█████. | ....█... | ......█. | ..██.... | ..█..... | ..█.█.█. | ..█.█.█. | ..█...█. | ..████.. | ..█...█. | ..████.. | ...███.. | ....█... | ..█...█. | ..█...█. | ..█.█.█. | ....█... | ....█... | ....█... | ..██.... | ....█... | .....██. | ...█.█.. | ........ | ........ | ....█... | ........ | ...█.█.. | ...███.. | ....█... | ...█.... | ........ | ..█..... | ......█. | ....█... | ..█████. | ........ | ..█████. | ........ | ....█... | ..█.█.█. | ....█... | ....██.. | ....██.. | ..█..█.. | ......█. | ..████.. | ....█... | ...███.. | ...████.
 | 0b4 | ..█.██.. | ..█████. | ..█...█. | ..█..... | ..█...█. | ..█..... | ..█..... | ..█..██. | ..█...█. | ....█... | ......█. | ..█.█... | ..█..... | ..█...█. | ..█..██. | ..█...█. | ..█..... | ..█.█.█. | ..█.█... | ......█. | ....█... | ..█...█. | ..█...█. | ..█.█.█. | ...█.█.. | ....█... | ...█.... | ..██.... | .....█.. | .....██. | ..█...█. | ........ | ........ | ....█... | ........ | ..█████. | ....█.█. | ...█.... | ..█.█.█. | ........ | ..█..... | ......█. | ...███.. | ....█... | ....█... | ........ | ........ | ...█.... | ..██..█. | ....█... | ...█.... | ......█. | ..█████. | ......█. | ..█...█. | ...█.... | ..█...█. | ......█.
 | 0b5 | ..█..... | ..█...█. | ..█...█. | ..█...█. | ..█...█. | ..█..... | ..█..... | ..█...█. | ..█...█. | ....█... | ..█...█. | ..█..█.. | ..█..... | ..█...█. | ..█...█. | ..█...█. | ..█..... | ..█..█.. | ..█..█.. | ..█...█. | ....█... | ..█...█. | ...█.█.. | ..██.██. | ..█...█. | ....█... | ..█..... | ..██.... | ......█. | .....██. | ........ | ........ | ........ | ........ | ........ | ...█.█.. | ..████.. | ..█..██. | ..█..█.. | ........ | ...█.... | .....█.. | ..█.█.█. | ....█... | ....█... | ........ | ........ | ..█..... | ..█...█. | ....█... | ..█..... | ..█...█. | .....█.. | ..█...█. | ..█...█. | ...█.... | ..█...█. | .....█..
 | 0b6 | ...████. | ..█...█. | ..████.. | ...███.. | ..████.. | ..█████. | ..█..... | ...████. | ..█...█. | ...███.. | ...███.. | ..█...█. | ..█████. | ..█...█. | ..█...█. | ...███.. | ..█..... | ...██.█. | ..█...█. | ...███.. | ....█... | ...███.. | ....█... | ..█...█. | ..█...█. | ....█... | ..█████. | ..█████. | ........ | ..█████. | ........ | ........ | ........ | ....█... | ........ | ...█.█.. | ....█... | .....██. | ...██.█. | ........ | ....█... | ....█... | ....█... | ........ | ...█.... | ........ | ....█... | ........ | ...███.. | ...███.. | ..█████. | ...███.. | .....█.. | ...███.. | ...███.. | ...█.... | ...███.. | ..███...
 | 0b7 | ........ | ........ | ........ | ........ | ........ | ........ | ........ | ........ | ........ | ........ | ........ | ........ | ........ | ........ | ........ | ........ | ........ | ........ | ........ | ........ | ........ | ........ | ........ | ........ | ........ | ........ | ........ | ........ | ........ | ........ | ........ | ..██████ | ........ | ........ | ........ | ........ | ........ | ........ | ........ | ........ | ........ | ........ | ........ | ........ | ........ | ........ | ........ | ........ | ........ | ........ | ........ | ........ | ........ | ........ | ........ | ........ | ........ | ........
 | ASCII DEC | 0 | 1 | 2 | 3 | 4 | 5 | 6 | 7 | 8 | 9 | 10 | 11 | 12 | 13 | 14 | 15 | 16 | 17 | 18 | 19 | 20 | 21 | 22 | 23 | 24 | 25 | 26 | 27 | 28 | 29 | 30 | 31 | 32 | 33 | 34 | 35 | 36 | 37 | 38 | 39 | 40 | 41 | 42 | 43 | 44 | 45 | 46 | 47 | 48 | 49 | 50 | 51 | 52 | 53 | 54 | 55 | 56 | 57
 | Char | #VALUE! | _x0001_ | _x0002_ | _x0003_ | _x0004_ | _x0005_ | _x0006_ | _x0007_ | _x0008_ |  |  | _x000B_ | _x000C_ | _x000D_ | _x000E_ | _x000F_ | _x0010_ | _x0011_ | _x0012_ | _x0013_ | _x0014_ | _x0015_ | _x0016_ | _x0017_ | _x0018_ | _x0019_ | _x001A_ | _x001B_ | _x001C_ | _x001D_ | _x001E_ | _x001F_ |  | ! | " | # | $ | % | & | ' | ( | ) | * | + | , | - | . | / | 0 | 1 | 2 | 3 | 4 | 5 | 6 | 7 | 8 | 9
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

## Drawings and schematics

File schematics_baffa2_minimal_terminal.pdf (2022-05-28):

A

A

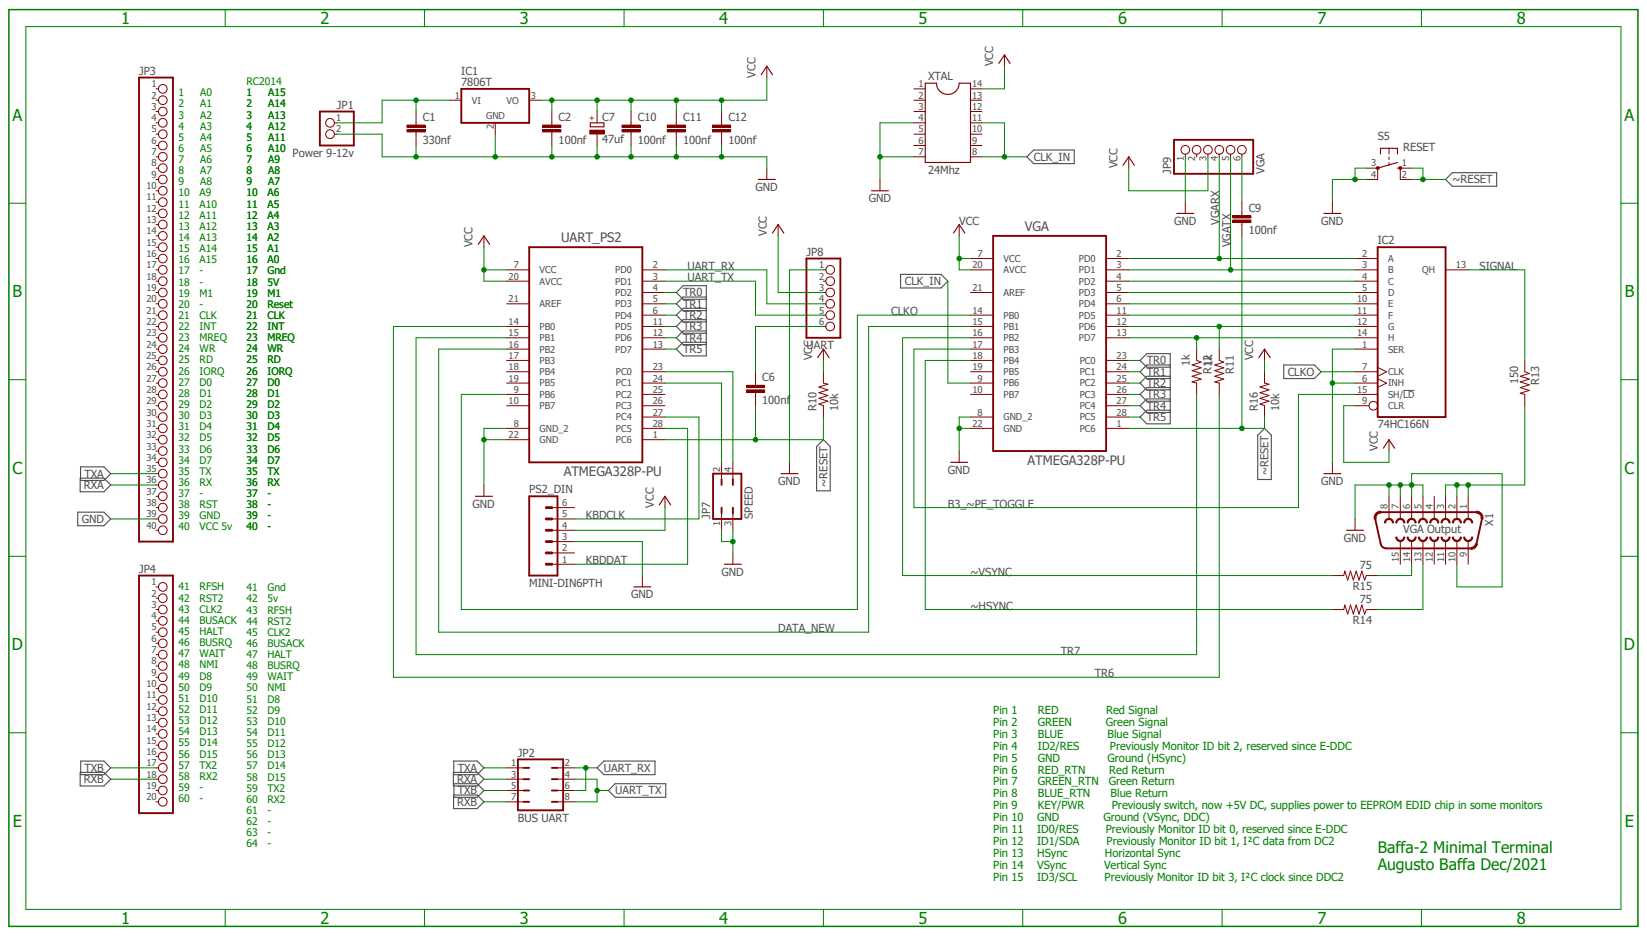
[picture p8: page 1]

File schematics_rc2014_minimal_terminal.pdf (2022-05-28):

A

A

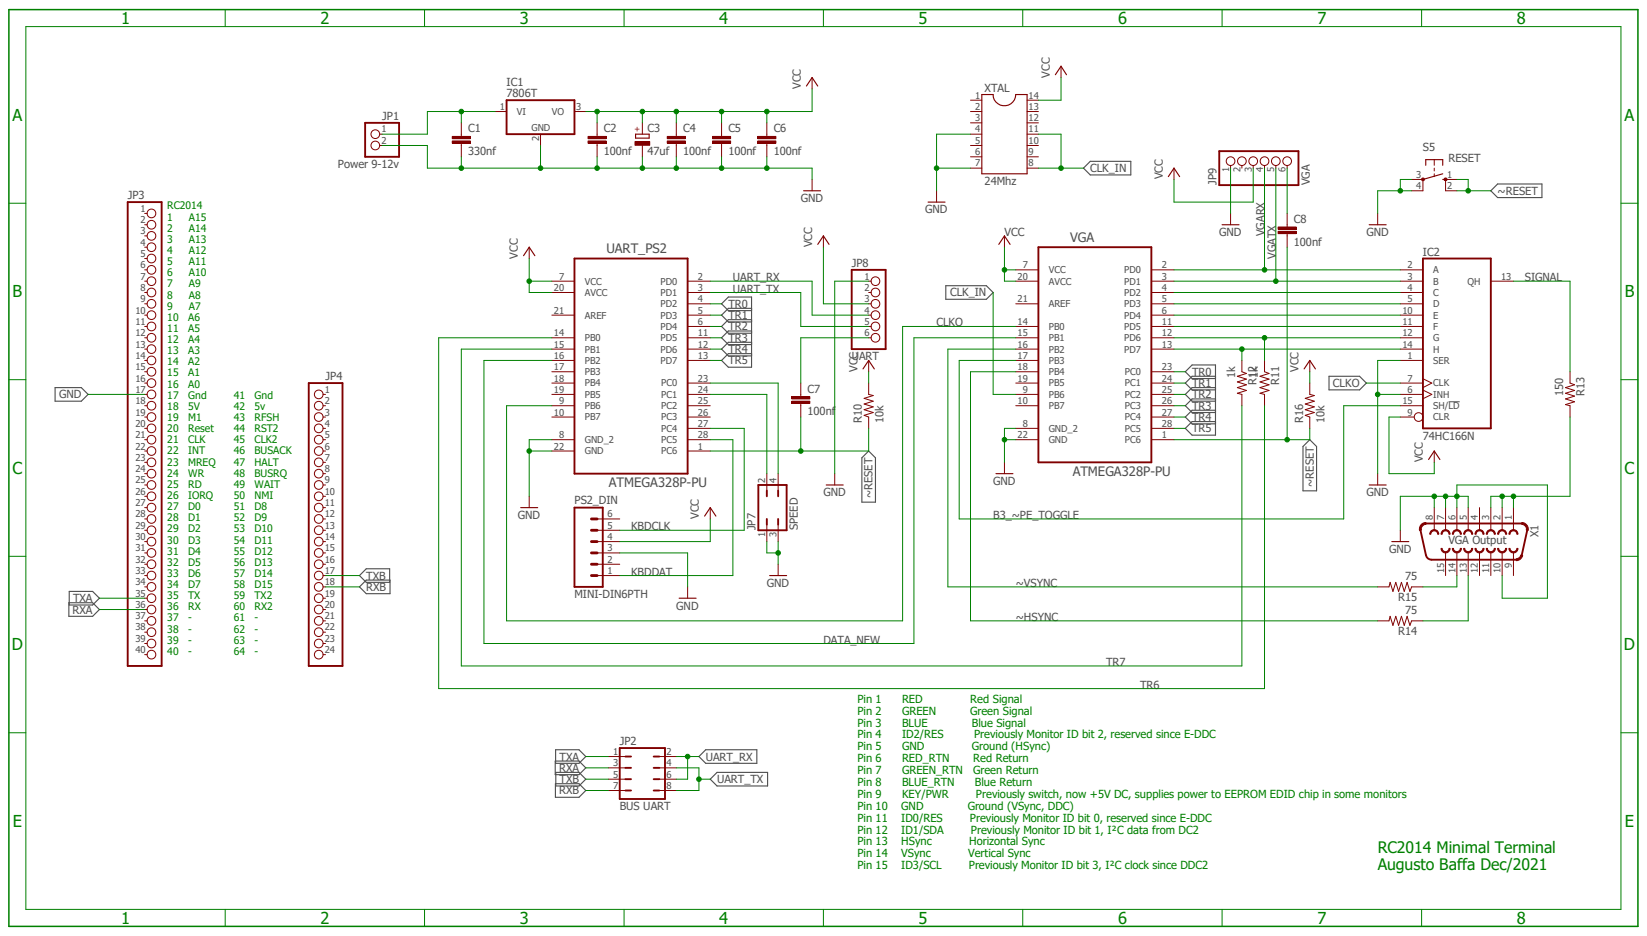
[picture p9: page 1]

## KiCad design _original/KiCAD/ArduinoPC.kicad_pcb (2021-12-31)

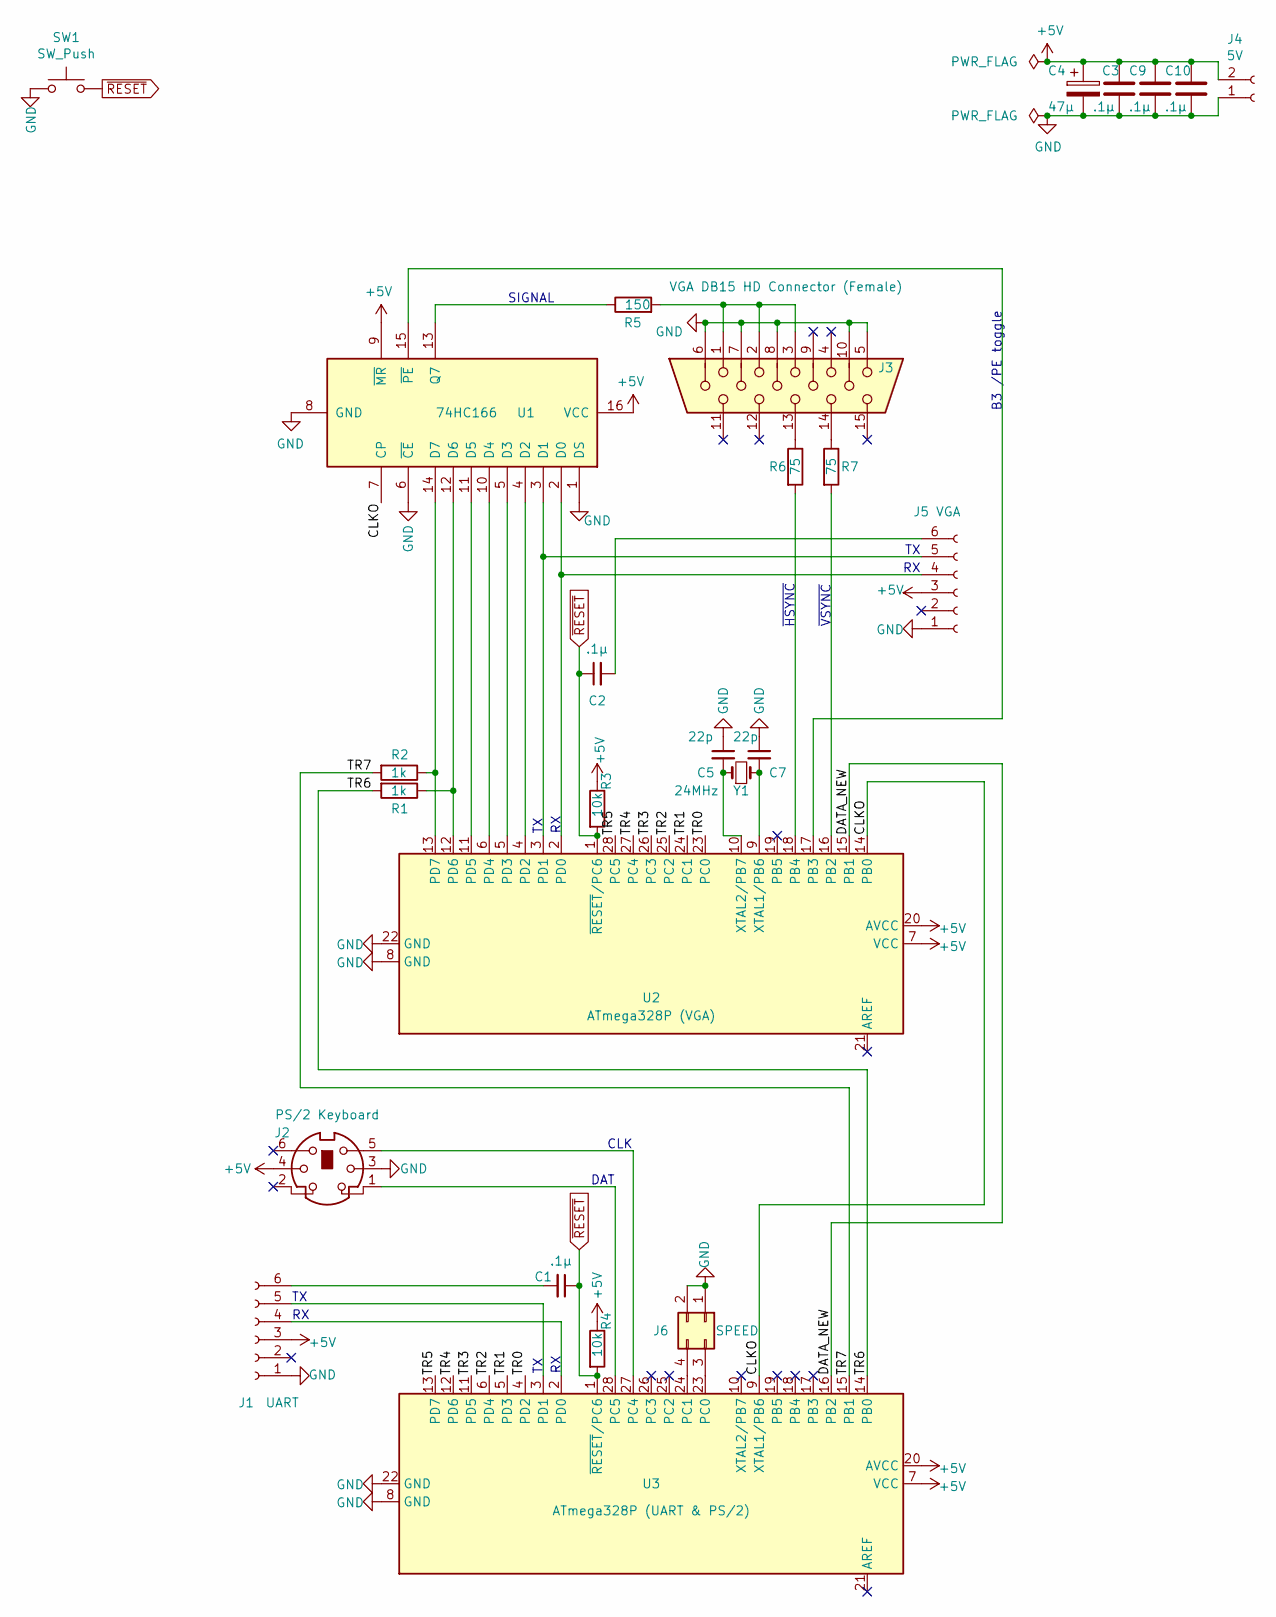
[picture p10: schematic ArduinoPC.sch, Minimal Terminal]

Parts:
C1, C2, C4, C9, C10: .1µ; C_Disc_D3.8mm_W2.6mm_P2.50mm
C3: 47µ; CP_Radial_D6.3mm_P2.50mm
C5, C7: 22p; C_Disc_D5.0mm_W2.5mm_P2.50mm
J1: UART; PinSocket_1x06_P2.54mm_Vertical
J2: PS/2 Keyboard; FP_MINI_DIN_6_PS2
J3: VGA DB15 HD Connector (Female); VGA DSUB15HD_female
J4: 5V; PinSocket_1x02_P2.54mm_Vertical
J5: VGA; PinSocket_1x06_P2.54mm_Vertical
J6: SPEED; PinHeader_2x02_P2.54mm_Vertical_Jumper
R1, R2: 1k; R_Axial_DIN0207_L6.3mm_D2.5mm_P7.62mm_Horizontal
R3, R4: 10k; R_Axial_DIN0207_L6.3mm_D2.5mm_P7.62mm_Horizontal
R5: 150; R_Axial_DIN0207_L6.3mm_D2.5mm_P7.62mm_Horizontal
R6, R7: 75; R_Axial_DIN0207_L6.3mm_D2.5mm_P7.62mm_Horizontal
SW1: SW_Push; SW_PUSH_6mm
U1: 74HC166; DIP-16_W7.62mm
U2: ATmega328P (VGA); DIP-28_W7.62mm_Socket
U3: ATmega328P (UART & PS/2); DIP-28_W7.62mm_Socket
Y1: 24MHz; Crystal_HC18-U_Vertical

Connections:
+5V: C3.1, C4.1, C9.1, C10.1, J1.3, J2.4, J4.2, J5.3, R3.1, R4.1, U1.9 (~MR), U1.16 (VCC), U2.7 (VCC), U2.20 (AVCC), U3.7 (VCC), U3.20 (AVCC)
/CLKO: U1.7 (CP), U2.14 (PB0), U3.9 (XTAL1/PB6)
/DATA_NEW: U2.15 (PB1), U3.16 (PB2)
/TR0: U2.23 (PC0), U3.4 (PD2)
/TR1: U2.24 (PC1), U3.5 (PD3)
/TR2: U2.25 (PC2), U3.6 (PD4)
/TR3: U2.26 (PC3), U3.11 (PD5)
/TR4: U2.27 (PC4), U3.12 (PD6)
/TR5: U2.28 (PC5), U3.13 (PD7)
/TR6: R1.2, U3.14 (PB0)
/TR7: R2.2, U3.15 (PB1)
GND: C3.2, C4.2, C5.1, C7.1, C9.2, C10.2, J1.1, J2.3, J3.5, J3.6, J3.7, J3.8, J3.10, J4.1, J5.1, J6.1, J6.2, SW1.1, U1.1 (DS), U1.6 (~CE), U1.8 (GND), U2.8 (GND), U2.22 (GND), U3.8 (GND), U3.22 (GND)
unnamed: C1.2, J1.6
unnamed: C2.2, J5.6
unnamed: C5.2, U2.10 (XTAL2/PB7), Y1.1
unnamed: C7.2, U2.9 (XTAL1/PB6), Y1.2
unnamed: J1.4, U3.2 (PD0)
unnamed: J1.5, U3.3 (PD1)
unnamed: J2.1, U3.28 (PC5)
unnamed: J2.5, U3.27 (PC4)
unnamed: J3.1, J3.2, J3.3, R5.2
unnamed: J3.13, R6.1
unnamed: J3.14, R7.1
unnamed: J5.4, U1.2 (D0), U2.2 (PD0)
unnamed: J5.5, U1.3 (D1), U2.3 (PD1)
unnamed: J6.3, U3.23 (PC0)
unnamed: J6.4, U3.24 (PC1)
unnamed: R1.1, U1.12 (D6), U2.12 (PD6)
unnamed: R2.1, U1.14 (D7), U2.13 (PD7)
unnamed: R5.1, U1.13 (Q7)
unnamed: R6.2, U2.18 (PB4)
unnamed: R7.2, U2.16 (PB2)
unnamed: U1.4 (D2), U2.4 (PD2)
unnamed: U1.5 (D3), U2.5 (PD3)
unnamed: U1.10 (D4), U2.6 (PD4)
unnamed: U1.11 (D5), U2.11 (PD5)
unnamed: U1.15 (~PE), U2.17 (PB3)
~RESET: C1.1, C2.1, R3.2, R4.2, SW1.2, U2.1 (~RESET~/PC6), U3.1 (~RESET~/PC6)

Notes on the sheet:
SIGNAL
~VSYNC
~HSYNC
B3 /PE toggle
DAT
CLK

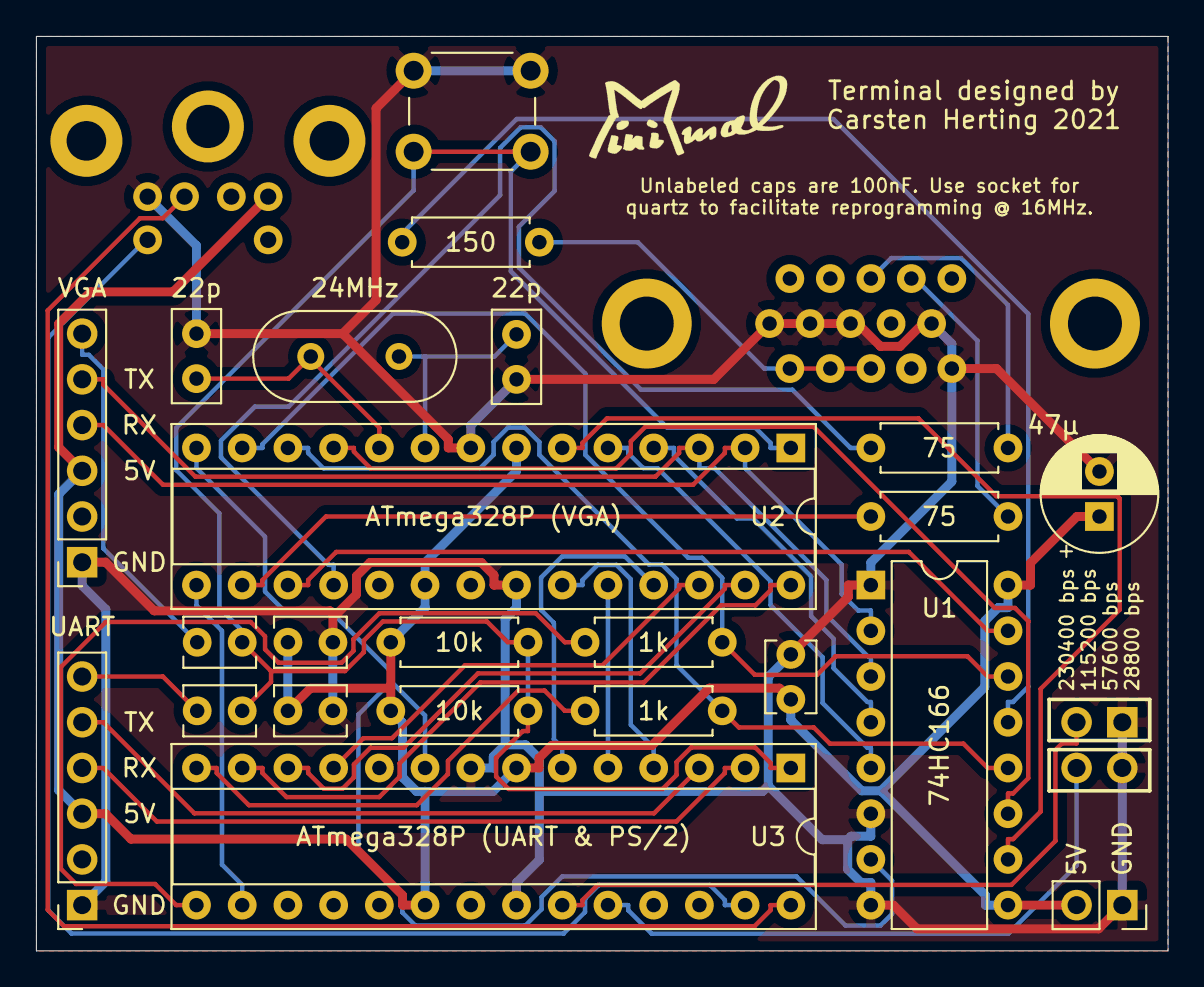
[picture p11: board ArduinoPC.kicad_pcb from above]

Board: 2 copper layers, 62.9 x 50.8 mm, 26 parts (0 on the bottom side), 38 nets.

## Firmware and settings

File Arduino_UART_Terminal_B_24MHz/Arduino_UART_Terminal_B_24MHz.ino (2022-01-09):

// ***************************************************************************
// *****                                                                 *****
// ***** AtMega328P UART ANSI Terminal with 60x25 Character VGA and PS/2 *****
// *****                                                                 *****
// *****        written by Carsten Herting 02.06.2021 Version 2.2        *****
// *****        US-International version by Augusto Baffa Dec/21         ***** 
// *****                                                                 *****
// ***************************************************************************
// Pin C0-5: terminal input bits 0-5
// Pin D0-7: parallel pixel output to 74166, in between: D6-7 terminal input bits 6-7
// Pin B0:   CLKO ATmega328 system clock output
// Pin B1:   DATA_NEW input handshake
// Pin B2:   /VSYNC VGA (timer1, every 1/60s, could also be done)
// Pin B3:   /PE low pulse (by hand inside ISR for 74166 /PE pixel shift register sync parallel load)
// Pin B4:   /HSYNC VGA (by hand inside ISR, every 32µs)
// Pin B5:   DATA_ACK output handshake
// See license at the end of this file.
//
// ** Fixed Escapes to clean line and screen jan, 6 2022 Augusto Baffa
// Fuse: BF | DA | FD | FF

#define WIDTH     60
#define HEIGHT    25

char row = 0, col = 0;            // current cursor position in terminal window
//char saved_row = 0, saved_col = 0;            // current cursor position in terminal window
//bool show_cursor = true;

volatile int vline = 0;           // current vertical position of pixel video output
volatile byte vram[HEIGHT][WIDTH];// array of VideoRAM
volatile char start = 0;          // start line of the VideoRAM (thus avoiding moving data while scrolling)
volatile int frames = 0;          // 1/60s frame counter for cursor blinking
volatile byte regout = 0;         // index of current output position in queue
volatile byte regin = 0;          // index of current input position in queue
volatile byte __attribute__ ((aligned (256))) reg[256];   // ring buffer data of keyboard input register

const volatile byte __attribute__ ((aligned (256))) charset[8][256] PROGMEM =
{
  0x00, 0x00, 0x00, 0x00, 0x00, 0x00, 0x00, 0x00, 0x00, 0x00, 0x00, 0x00, 0x00, 0x00, 0x00, 0x00, 0x00, 0x00, 0x00, 0x00, 0x00, 0x00, 0x00, 0x00, 0x00, 0x00, 0x00, 0x00, 0x00, 0x00, 0x03, 0xC0, 0x00, 0x18, 0x66, 0x66, 0x18, 0x62, 0x3C, 0x06, 0x0C, 0x30, 0x00, 0x00, 0x00, 0x00, 0x00, 0x00, 0x3C, 0x18, 0x3C, 0x3C, 0x06, 0x7E, 0x3C, 0x7E, 0x3C, 0x3C, 0x00, 0x00, 0x0E, 0x00, 0x70, 0x3C, 0x3C, 0x18, 0x7C, 0x3C, 0x78, 0x7E, 0x7E, 0x3C, 0x66, 0x3C, 0x1E, 0x66, 0x60, 0x63, 0x66, 0x3C, 0x7C, 0x3C, 0x7C, 0x3C, 0x7E, 0x66, 0x66, 0x63, 0x66, 0x66, 0x7E, 0x3C, 0x00, 0x3C, 0x00, 0x00, 0x60, 0x00, 0x00, 0x00, 0x00, 0x00, 0x00, 0x00, 0x00, 0x00, 0x00, 0x00, 0x00, 0x00, 0x00, 0x00, 0x00, 0x00, 0x00, 0x00, 0x00, 0x00, 0x00, 0x00, 0x00, 0x00, 0x00, 0x0E, 0x18, 0x70, 0x00, 0x00, 0x00, 0x00, 0x00, 0x18, 0x18, 0x18, 0x18, 0x18, 0x18, 0x00, 0x00, 0x00, 0x18, 0x18, 0xFF, 0xFF, 0x01, 0x80, 0x0F, 0xF0, 0xFF, 0x00, 0x0F, 0xF0, 0xFF, 0x00, 0x0F, 0xF0, 0xFF, 0x00, 0x0F, 0xF0, 0xFF, 0xE7, 0x99, 0x99, 0xE7, 0x9D, 0xC3, 0xF9, 0xF3, 0xCF, 0xFF, 0xFF, 0xFF, 0xFF, 0xFF, 0xFF, 0xC3, 0xE7, 0xC3, 0xC3, 0xF9, 0x81, 0xC3, 0x81, 0xC3, 0xC3, 0xFF, 0xFF, 0xF1, 0xFF, 0x8F, 0xC3, 0xC3, 0xE7, 0x83, 0xC3, 0x87, 0x81, 0x81, 0xC3, 0x99, 0xC3, 0xE1, 0x99, 0x9F, 0x9C, 0x99, 0xC3, 0x83, 0xC3, 0x83, 0xC3, 0x81, 0x99, 0x99, 0x9C, 0x99, 0x99, 0x81, 0xC3, 0xFF, 0xC3, 0xFF, 0xFF, 0x9F, 0xFF, 0xFF, 0xFF, 0xFF, 0xFF, 0xFF, 0xFF, 0xFF, 0xFF, 0xFF, 0xFF, 0xFF, 0xFF, 0xFF, 0xFF, 0xFF, 0xFF, 0xFF, 0xFF, 0xFF, 0xFF, 0xFF, 0xFF, 0xFF, 0xFF, 0xFF, 0xF1, 0xE7, 0x8F, 0xFF, 0xFF,
  0x00, 0x00, 0x00, 0x00, 0x00, 0x00, 0x00, 0x00, 0x00, 0x00, 0x00, 0x00, 0x00, 0x00, 0x00, 0x00, 0x00, 0x00, 0x00, 0x00, 0x00, 0x00, 0x00, 0x00, 0x00, 0x00, 0x00, 0x00, 0x00, 0x00, 0x07, 0xE0, 0x00, 0x18, 0x66, 0x66, 0x3E, 0x66, 0x66, 0x0C, 0x18, 0x18, 0x66, 0x18, 0x00, 0x00, 0x00, 0x03, 0x66, 0x18, 0x66, 0x66, 0x0E, 0x60, 0x66, 0x66, 0x66, 0x66, 0x00, 0x00, 0x18, 0x00, 0x18, 0x66, 0x66, 0x3C, 0x66, 0x66, 0x6C, 0x60, 0x60, 0x66, 0x66, 0x18, 0x0C, 0x6C, 0x60, 0x77, 0x76, 0x66, 0x66, 0x66, 0x66, 0x66, 0x18, 0x66, 0x66, 0x63, 0x66, 0x66, 0x06, 0x30, 0x60, 0x0C, 0x18, 0x00, 0x30, 0x00, 0x60, 0x00, 0x06, 0x00, 0x0E, 0x00, 0x60, 0x18, 0x06, 0x60, 0x38, 0x00, 0x00, 0x00, 0x00, 0x00, 0x00, 0x00, 0x18, 0x00, 0x00, 0x00, 0x00, 0x00, 0x00, 0x18, 0x18, 0x18, 0x00, 0x10, 0x00, 0x00, 0x00, 0x18, 0x18, 0x18, 0x18, 0x18, 0x18, 0x00, 0x00, 0x00, 0x18, 0x18, 0x7F, 0xFE, 0x03, 0xC0, 0x0F, 0xF0, 0xFF, 0x00, 0x0F, 0xF0, 0xFF, 0x00, 0x0F, 0xF0, 0xFF, 0x00, 0x0F, 0xF0, 0xFF, 0xE7, 0x99, 0x99, 0xC1, 0x99, 0x99, 0xF3, 0xE7, 0xE7, 0x99, 0xE7, 0xFF, 0xFF, 0xFF, 0xFC, 0x99, 0xE7, 0x99, 0x99, 0xF1, 0x9F, 0x99, 0x99, 0x99, 0x99, 0xFF, 0xFF, 0xE7, 0xFF, 0xE7, 0x99, 0x99, 0xC3, 0x99, 0x99, 0x93, 0x9F, 0x9F, 0x99, 0x99, 0xE7, 0xF3, 0x93, 0x9F, 0x88, 0x89, 0x99, 0x99, 0x99, 0x99, 0x99, 0xE7, 0x99, 0x99, 0x9C, 0x99, 0x99, 0xF9, 0xCF, 0x9F, 0xF3, 0xE7, 0xFF, 0xCF, 0xFF, 0x9F, 0xFF, 0xF9, 0xFF, 0xF1, 0xFF, 0x9F, 0xE7, 0xF9, 0x9F, 0xC7, 0xFF, 0xFF, 0xFF, 0xFF, 0xFF, 0xFF, 0xFF, 0xE7, 0xFF, 0xFF, 0xFF, 0xFF, 0xFF, 0xFF, 0xE7, 0xE7, 0xE7, 0xFF, 0xEF,
  0x00, 0x00, 0x00, 0x00, 0x00, 0x00, 0x00, 0x00, 0x00, 0x00, 0x00, 0x00, 0x00, 0x00, 0x00, 0x00, 0x00, 0x00, 0x00, 0x00, 0x00, 0x00, 0x00, 0x00, 0x00, 0x00, 0x00, 0x00, 0x00, 0x00, 0x0E, 0x70, 0x00, 0x18, 0x66, 0xFF, 0x60, 0x0C, 0x3C, 0x18, 0x30, 0x0C, 0x3C, 0x18, 0x00, 0x00, 0x00, 0x06, 0x6E, 0x38, 0x06, 0x06, 0x1E, 0x7C, 0x60, 0x0C, 0x66, 0x66, 0x18, 0x18, 0x30, 0x7E, 0x0C, 0x06, 0x6E, 0x66, 0x66, 0x60, 0x66, 0x60, 0x60, 0x60, 0x66, 0x18, 0x0C, 0x78, 0x60, 0x7F, 0x7E, 0x66, 0x66, 0x66, 0x66, 0x60, 0x18, 0x66, 0x66, 0x63, 0x3C, 0x66, 0x0C, 0x30, 0x30, 0x0C, 0x3C, 0x00, 0x18, 0x3C, 0x60, 0x3C, 0x06, 0x3C, 0x18, 0x3E, 0x60, 0x00, 0x00, 0x60, 0x18, 0x66, 0x7C, 0x3C, 0x7C, 0x3E, 0x7C, 0x3E, 0x7E, 0x66, 0x66, 0x63, 0x66, 0x66, 0x7E, 0x18, 0x18, 0x18, 0x00, 0x30, 0x00, 0x00, 0x00, 0x18, 0x18, 0x18, 0x18, 0x18, 0x18, 0x00, 0x00, 0x00, 0x1C, 0x38, 0x3F, 0xFC, 0x07, 0xE0, 0x0F, 0xF0, 0xFF, 0x00, 0x0F, 0xF0, 0xFF, 0x00, 0x0F, 0xF0, 0xFF, 0x00, 0x0F, 0xF0, 0xFF, 0xE7, 0x99, 0x00, 0x9F, 0xF3, 0xC3, 0xE7, 0xCF, 0xF3, 0xC3, 0xE7, 0xFF, 0xFF, 0xFF, 0xF9, 0x91, 0xC7, 0xF9, 0xF9, 0xE1, 0x83, 0x9F, 0xF3, 0x99, 0x99, 0xE7, 0xE7, 0xCF, 0x81, 0xF3, 0xF9, 0x91, 0x99, 0x99, 0x9F, 0x99, 0x9F, 0x9F, 0x9F, 0x99, 0xE7, 0xF3, 0x87, 0x9F, 0x80, 0x81, 0x99, 0x99, 0x99, 0x99, 0x9F, 0xE7, 0x99, 0x99, 0x9C, 0xC3, 0x99, 0xF3, 0xCF, 0xCF, 0xF3, 0xC3, 0xFF, 0xE7, 0xC3, 0x9F, 0xC3, 0xF9, 0xC3, 0xE7, 0xC1, 0x9F, 0xFF, 0xFF, 0x9F, 0xE7, 0x99, 0x83, 0xC3, 0x83, 0xC1, 0x83, 0xC1, 0x81, 0x99, 0x99, 0x9C, 0x99, 0x99, 0x81, 0xE7, 0xE7, 0xE7, 0xFF, 0xCF,
  0x00, 0x00, 0x00, 0x00, 0x00, 0x00, 0x00, 0x00, 0x00, 0x00, 0x00, 0x00, 0x00, 0x00, 0x00, 0x00, 0x00, 0x00, 0x00, 0x00, 0x00, 0x00, 0x00, 0x00, 0x00, 0x00, 0x00, 0x00, 0x00, 0x00, 0x1C, 0x38, 0x00, 0x18, 0x00, 0x66, 0x3C, 0x18, 0x38, 0x00, 0x30, 0x0C, 0xFF, 0x7E, 0x00, 0x7E, 0x00, 0x0C, 0x76, 0x18, 0x0C, 0x1C, 0x66, 0x06, 0x7C, 0x18, 0x3C, 0x3E, 0x00, 0x00, 0x60, 0x00, 0x06, 0x0C, 0x6E, 0x7E, 0x7C, 0x60, 0x66, 0x78, 0x78, 0x6E, 0x7E, 0x18, 0x0C, 0x70, 0x60, 0x6B, 0x7E, 0x66, 0x7C, 0x66, 0x7C, 0x3C, 0x18, 0x66, 0x66, 0x6B, 0x18, 0x3C, 0x18, 0x30, 0x18, 0x0C, 0x66, 0x00, 0x00, 0x06, 0x7C, 0x60, 0x3E, 0x66, 0x3E, 0x66, 0x7C, 0x38, 0x06, 0x6C, 0x18, 0x7F, 0x66, 0x66, 0x66, 0x66, 0x66, 0x60, 0x18, 0x66, 0x66, 0x6B, 0x3C, 0x66, 0x0C, 0x70, 0x18, 0x0E, 0x3B, 0x7F, 0x1F, 0xFF, 0xF8, 0x1F, 0xFF, 0xF8, 0x1F, 0xFF, 0xF8, 0xFF, 0x07, 0xE0, 0x0F, 0xF0, 0x1F, 0xF8, 0x0F, 0xF0, 0x0F, 0xF0, 0xFF, 0x00, 0x0F, 0xF0, 0xFF, 0x00, 0x0F, 0xF0, 0xFF, 0x00, 0x0F, 0xF0, 0xFF, 0xE7, 0xFF, 0x99, 0xC3, 0xE7, 0xC7, 0xFF, 0xCF, 0xF3, 0x00, 0x81, 0xFF, 0x81, 0xFF, 0xF3, 0x89, 0xE7, 0xF3, 0xE3, 0x99, 0xF9, 0x83, 0xE7, 0xC3, 0xC1, 0xFF, 0xFF, 0x9F, 0xFF, 0xF9, 0xF3, 0x91, 0x81, 0x83, 0x9F, 0x99, 0x87, 0x87, 0x91, 0x81, 0xE7, 0xF3, 0x8F, 0x9F, 0x94, 0x81, 0x99, 0x83, 0x99, 0x83, 0xC3, 0xE7, 0x99, 0x99, 0x94, 0xE7, 0xC3, 0xE7, 0xCF, 0xE7, 0xF3, 0x99, 0xFF, 0xFF, 0xF9, 0x83, 0x9F, 0xC1, 0x99, 0xC1, 0x99, 0x83, 0xC7, 0xF9, 0x93, 0xE7, 0x80, 0x99, 0x99, 0x99, 0x99, 0x99, 0x9F, 0xE7, 0x99, 0x99, 0x94, 0xC3, 0x99, 0xF3, 0x8F, 0xE7, 0xF1, 0xC4, 0x80,
  0x00, 0x00, 0x00, 0x00, 0x00, 0x00, 0x00, 0x00, 0x00, 0x00, 0x00, 0x00, 0x00, 0x00, 0x00, 0x00, 0x00, 0x00, 0x00, 0x00, 0x00, 0x00, 0x00, 0x00, 0x00, 0x00, 0x00, 0x00, 0x00, 0x00, 0x38, 0x1C, 0x00, 0x00, 0x00, 0xFF, 0x06, 0x30, 0x67, 0x00, 0x30, 0x0C, 0x3C, 0x18, 0x00, 0x00, 0x00, 0x18, 0x66, 0x18, 0x30, 0x06, 0x7F, 0x06, 0x66, 0x18, 0x66, 0x06, 0x00, 0x00, 0x30, 0x7E, 0x0C, 0x18, 0x60, 0x66, 0x66, 0x60, 0x66, 0x60, 0x60, 0x66, 0x66, 0x18, 0x0C, 0x78, 0x60, 0x63, 0x6E, 0x66, 0x60, 0x66, 0x78, 0x06, 0x18, 0x66, 0x66, 0x7F, 0x3C, 0x18, 0x30, 0x30, 0x0C, 0x0C, 0x00, 0x00, 0x00, 0x3E, 0x66, 0x60, 0x66, 0x7E, 0x18, 0x66, 0x66, 0x18, 0x06, 0x78, 0x18, 0x7F, 0x66, 0x66, 0x66, 0x66, 0x60, 0x3C, 0x18, 0x66, 0x66, 0x7F, 0x18, 0x66, 0x18, 0x18, 0x18, 0x18, 0x6E, 0x7F, 0x1F, 0xFF, 0xF8, 0x1F, 0xFF, 0xF8, 0x1F, 0xFF, 0xF8, 0xFF, 0x0F, 0xF0, 0x07, 0xE0, 0x0F, 0xF0, 0x1F, 0xF8, 0x00, 0x00, 0x00, 0x0F, 0x0F, 0x0F, 0x0F, 0xF0, 0xF0, 0xF0, 0xF0, 0xFF, 0xFF, 0xFF, 0xFF, 0xFF, 0xFF, 0x00, 0xF9, 0xCF, 0x98, 0xFF, 0xCF, 0xF3, 0xC3, 0xE7, 0xFF, 0xFF, 0xFF, 0xE7, 0x99, 0xE7, 0xCF, 0xF9, 0x80, 0xF9, 0x99, 0xE7, 0x99, 0xF9, 0xFF, 0xFF, 0xCF, 0x81, 0xF3, 0xE7, 0x9F, 0x99, 0x99, 0x9F, 0x99, 0x9F, 0x9F, 0x99, 0x99, 0xE7, 0xF3, 0x87, 0x9F, 0x9C, 0x91, 0x99, 0x9F, 0x99, 0x87, 0xF9, 0xE7, 0x99, 0x99, 0x80, 0xC3, 0xE7, 0xCF, 0xCF, 0xF3, 0xF3, 0xFF, 0xFF, 0xFF, 0xC1, 0x99, 0x9F, 0x99, 0x81, 0xE7, 0x99, 0x99, 0xE7, 0xF9, 0x87, 0xE7, 0x80, 0x99, 0x99, 0x99, 0x99, 0x9F, 0xC3, 0xE7, 0x99, 0x99, 0x80, 0xE7, 0x99, 0xE7, 0xE7, 0xE7, 0xE7, 0x91, 0x80,
  0x00, 0x00, 0x00, 0x00, 0x00, 0x00, 0x00, 0x00, 0x00, 0x00, 0x00, 0x00, 0x00, 0x00, 0x00, 0x00, 0x00, 0x00, 0x00, 0x00, 0x00, 0x00, 0x00, 0x00, 0x00, 0x00, 0x00, 0x00, 0x00, 0x00, 0x70, 0x0E, 0x00, 0x00, 0x00, 0x66, 0x7C, 0x66, 0x66, 0x00, 0x18, 0x18, 0x66, 0x18, 0x18, 0x00, 0x18, 0x30, 0x66, 0x18, 0x60, 0x66, 0x06, 0x66, 0x66, 0x18, 0x66, 0x66, 0x18, 0x18, 0x18, 0x00, 0x18, 0x00, 0x66, 0x66, 0x66, 0x66, 0x6C, 0x60, 0x60, 0x66, 0x66, 0x18, 0x6C, 0x6C, 0x60, 0x63, 0x66, 0x66, 0x60, 0x3C, 0x6C, 0x66, 0x18, 0x66, 0x3C, 0x77, 0x66, 0x18, 0x60, 0x30, 0x06, 0x0C, 0x00, 0x00, 0x00, 0x66, 0x66, 0x60, 0x66, 0x60, 0x18, 0x3E, 0x66, 0x18, 0x06, 0x6C, 0x18, 0x6B, 0x66, 0x66, 0x7C, 0x3E, 0x60, 0x06, 0x18, 0x66, 0x3C, 0x3E, 0x3C, 0x3E, 0x30, 0x18, 0x18, 0x18, 0x00, 0x30, 0x18, 0x18, 0x18, 0x18, 0x18, 0x18, 0x00, 0x00, 0x00, 0x00, 0x1C, 0x38, 0x00, 0x00, 0x07, 0xE0, 0x3F, 0xFC, 0x00, 0x00, 0x00, 0x0F, 0x0F, 0x0F, 0x0F, 0xF0, 0xF0, 0xF0, 0xF0, 0xFF, 0xFF, 0xFF, 0xFF, 0xFF, 0xFF, 0x99, 0x83, 0x99, 0x99, 0xFF, 0xE7, 0xE7, 0x99, 0xE7, 0xE7, 0xFF, 0xE7, 0xCF, 0x99, 0xE7, 0x9F, 0x99, 0xF9, 0x99, 0x99, 0xE7, 0x99, 0x99, 0xE7, 0xE7, 0xE7, 0xFF, 0xE7, 0xFF, 0x99, 0x99, 0x99, 0x99, 0x93, 0x9F, 0x9F, 0x99, 0x99, 0xE7, 0x93, 0x93, 0x9F, 0x9C, 0x99, 0x99, 0x9F, 0xC3, 0x93, 0x99, 0xE7, 0x99, 0xC3, 0x88, 0x99, 0xE7, 0x9F, 0xCF, 0xF9, 0xF3, 0xFF, 0xFF, 0xFF, 0x99, 0x99, 0x9F, 0x99, 0x9F, 0xE7, 0xC1, 0x99, 0xE7, 0xF9, 0x93, 0xE7, 0x94, 0x99, 0x99, 0x83, 0xC1, 0x9F, 0xF9, 0xE7, 0x99, 0xC3, 0xC1, 0xC3, 0xC1, 0xCF, 0xE7, 0xE7, 0xE7, 0xFF, 0xCF,
  0x00, 0x00, 0x00, 0x00, 0x00, 0x00, 0x00, 0x00, 0x00, 0x00, 0x00, 0x00, 0x00, 0x00, 0x00, 0x00, 0x00, 0x00, 0x00, 0x00, 0x00, 0x00, 0x00, 0x00, 0x00, 0x00, 0x00, 0x00, 0x00, 0x00, 0xE0, 0x07, 0x00, 0x18, 0x00, 0x66, 0x18, 0x46, 0x3F, 0x00, 0x0C, 0x30, 0x00, 0x00, 0x18, 0x00, 0x18, 0x60, 0x3C, 0x7E, 0x7E, 0x3C, 0x06, 0x3C, 0x3C, 0x18, 0x3C, 0x3C, 0x00, 0x18, 0x0E, 0x00, 0x70, 0x18, 0x3C, 0x66, 0x7C, 0x3C, 0x78, 0x7E, 0x60, 0x3C, 0x66, 0x3C, 0x38, 0x66, 0x7E, 0x63, 0x66, 0x3C, 0x60, 0x0E, 0x66, 0x3C, 0x18, 0x3C, 0x18, 0x63, 0x66, 0x18, 0x7E, 0x3C, 0x03, 0x3C, 0x00, 0x00, 0x00, 0x3E, 0x7C, 0x3C, 0x3E, 0x3C, 0x18, 0x06, 0x66, 0x3C, 0x06, 0x66, 0x3C, 0x63, 0x66, 0x3C, 0x60, 0x06, 0x60, 0x7C, 0x0E, 0x3E, 0x18, 0x36, 0x66, 0x0C, 0x7E, 0x0E, 0x18, 0x70, 0x00, 0x10, 0x18, 0x18, 0x18, 0x18, 0x18, 0x18, 0x00, 0x00, 0x00, 0x00, 0x18, 0x18, 0x00, 0x00, 0x03, 0xC0, 0x7F, 0xFE, 0x00, 0x00, 0x00, 0x0F, 0x0F, 0x0F, 0x0F, 0xF0, 0xF0, 0xF0, 0xF0, 0xFF, 0xFF, 0xFF, 0xFF, 0xE7, 0xFF, 0x99, 0xE7, 0xB9, 0xC0, 0xFF, 0xF3, 0xCF, 0xFF, 0xFF, 0xE7, 0xFF, 0xE7, 0x9F, 0xC3, 0x81, 0x81, 0xC3, 0xF9, 0xC3, 0xC3, 0xE7, 0xC3, 0xC3, 0xFF, 0xE7, 0xF1, 0xFF, 0x8F, 0xE7, 0xC3, 0x99, 0x83, 0xC3, 0x87, 0x81, 0x9F, 0xC3, 0x99, 0xC3, 0xC7, 0x99, 0x81, 0x9C, 0x99, 0xC3, 0x9F, 0xF1, 0x99, 0xC3, 0xE7, 0xC3, 0xE7, 0x9C, 0x99, 0xE7, 0x81, 0xC3, 0xFC, 0xC3, 0xFF, 0xFF, 0xFF, 0xC1, 0x83, 0xC3, 0xC1, 0xC3, 0xE7, 0xF9, 0x99, 0xC3, 0xF9, 0x99, 0xC3, 0x9C, 0x99, 0xC3, 0x9F, 0xF9, 0x9F, 0x83, 0xF1, 0xC1, 0xE7, 0xC9, 0x99, 0xF3, 0x81, 0xF1, 0xE7, 0x8F, 0xFF, 0xEF,
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
int main() { setup(); while (true) loop(); }      // enforce main() loop w/o serial handler

ISR(TIMER1_OVF_vect) { vline = 0; frames++; }     // timer1 overflow interrupt resets vline at HSYNC

// *****************************************************************
// *****                                                       *****
// ***** ANSI Terminal Implementation (add new functions here) *****
// *****                                                       *****
// *****************************************************************
void ProcessChar(byte inbyte)                     // processes a character (accepts some VT52/GEMDOS ESC sequences, control chars, normal chars)
{
  static bool reverse = false;
  static byte escvalid = 0;                       // Number of valid characters in escbuffer[]
  static byte esccount = 0;
  static byte escbuffer[5] = { 0,0,0,0,0 };
  byte anz;
  byte r;
  frames = 30;                                    // make cursor invisible for a very short time after receiving a character

  if (escvalid > 11) escvalid = 0;                 // Delete unprocessable ESC sequences and process this character normally
  if (esccount >= 5) escvalid = 0;                 // Delete unprocessable ESC sequences and process this character normally
  
  
  if (inbyte == 27) { 
    escvalid = 1; 
    esccount = 0;
    memset((void*)escbuffer, 0, 5);
    
    return; 
   }     // start new ESC sequence

  
  if (escvalid > 0)                               // AN ESC IS ALREADY ACTIVE
  {
    if (escvalid < 2)
    {
      if (inbyte == '[') escvalid++;              // '[' MUST come as the 2nd character
      else escvalid = 0;
    }
    else if(inbyte == 0x20) // ignore espaces while in escape mode
      return;
    else                                          // '\e[' has already been received correctly ...
    {
      //escbuffer[escvalid++] = inbyte;             // add another character
      escvalid++;
      switch (inbyte)                             // For each ESC sequence it must be checked whether the command is complete
      {

        case '0': case '1': case '2': case '3': case '4': case '5': case '6': case '7': case '8': case '9':{   // add numbers to ESC sequence
          
          escbuffer[esccount] *= 10;
          escbuffer[esccount] += inbyte - 48;
          break; 
        }
        
        case ';': { //case '?': 
          esccount++;
          break;
        }
               
 
        case 'A':                                // ESC[#A  moves cursor up # lines
        {
          anz = escbuffer[esccount] > 0 ? escbuffer[esccount] : 1;
          for (r = 0; r < anz; r++) if (row != start) { row--; if (row < 0) row = HEIGHT-1; }
          escvalid = 0; break;
        }
        
        case 'B':                                // ESC[#B  moves cursor down # lines
        {
          anz = escbuffer[esccount] > 0 ? escbuffer[esccount] : 1;
          for (r = 0; r < anz; r++) { byte oldrow = row; row++; if (row > HEIGHT-1) row = 0; if (row == start) row = oldrow; }
          escvalid = 0; break;
        }
        
        case 'C':                                // ESC[#C  moves cursor right # columns
        {
          anz = escbuffer[esccount] > 0 ? escbuffer[esccount] : 1;
          for (r = 0; r < anz; r++) if (col < WIDTH-1) col++;
          escvalid = 0; break;
        }
        
        case 'D':                                // ESC[#D  moves cursor left # columns
        {
          anz = escbuffer[esccount] > 0 ? escbuffer[esccount] : 1;
          for (r = 0; r < anz; r++) if (col > 0) col--;
          escvalid = 0; break;
        }

        case 'd':                                // move cursor to an absolute x position (left border: 1)
        {

          if (escbuffer[esccount] > 0)
          {
            row = start + min(HEIGHT-1, max(0, escbuffer[esccount]-1));
            if (row > HEIGHT-1) row -=HEIGHT;
          }
          else row = start;
          escvalid = 0; break;
        }

        case 'E':                                // ESC[#E  moves cursor to beginning of next line, # lines down
        {
          col = 0;
          anz = escbuffer[esccount] > 0 ? escbuffer[esccount] : 1;
          for (r = 0; r < anz; r++) { byte oldrow = row; row++; if (row > HEIGHT-1) row = 0; if (row == start) row = oldrow; }
          escvalid = 0; break;
        }
        
        case 'F':                                // ESC[#F  moves cursor to beginning of previous line, # lines up
        {
          col = 0;
          anz = escbuffer[esccount] > 0 ? escbuffer[esccount] : 1;
          for (r = 0; r < anz; r++) if (row != start) { row--; if (row < 0) row = HEIGHT-1; }
          escvalid = 0; break;
        }        

        case 'G':                                // ESC[#G  moves cursor to column #
        {
          if (escbuffer[esccount] > 0)          
            col = min(WIDTH-1, max(0, escbuffer[esccount]-1));
          else col = 0;
          escvalid = 0; break;
        }
       
        case 'H': case 'f':{                     // move cursor to upper left corner

          if(esccount == 1){

            row = start + min(HEIGHT-1, max(0, escbuffer[0]-1));
            if (row > HEIGHT-1) row -=HEIGHT;
            
            col = min(WIDTH-1,  max(0, escbuffer[1]-1));
          }
          else{
            row = start; col = 0;
          }
          escvalid = 0; break;
        }

/*
        case 'h':{                    // Cursor visible
          //if (escbuffer[1] == 25) show_cursor = true;                              
          escvalid = 0;   
        }
*/
      
        case 'J':                                // clear VRAM from cursor onwards
        {
          anz = escbuffer[esccount];

          switch(anz){
            case 0:{            // erase from cursor until end of screen
              r = row;
              memset((void*)&vram[r++][col], 32, WIDTH-col);              
              while (r != start && r < HEIGHT){
                memset((void*)&vram[r++][0], 32, WIDTH); 
              } 
              break;
            }
          
            case 1:{            //erase from cursor to beginning of screen
              r = row;
              memset((void*)&vram[r][0], 32, col+1);
              if(r > 0){
                do{
                  memset((void*)&vram[--r][0], 32, WIDTH);
                } while (r > 0);
              }
              break;
            }

            case 2:case 3:{            // erase entire screen
              start = 0;
              row = 0;
              col = 0;
              memset((void*)vram, 32, WIDTH * HEIGHT);   // clear the entire VRAM
              break;
            }
          }
          
          escvalid = 0; 
          break;
        }
        
        case 'K':                                // clear line from cursor onwards (does not move the cursor)
          anz = escbuffer[esccount];

          switch(anz){
            case 0:{ 
              memset((void*)&vram[row][col], 32, WIDTH-col);  // ESC[K = ESC[0K erase from cursor to end of line
              break;
            }
            case 1:{          // erase start of line to the cursor
              memset((void*)&vram[row][0], 32, col+1);
              break;
            }
            case 2:{          // erase the entire line
              memset((void*)&vram[row][0], 32, WIDTH);
              break;
            }
          }
          
          escvalid = 0; 
          
          break;

/*
        case 'l':{                    // Cursor invisible
          if (escbuffer[1] == 25) show_cursor = false;                              
          escvalid = 0;   
        }
*/
        
        case 'm':                            
        {

          for(r = 0; r <=esccount; r++){
            anz = escbuffer[r];
            switch(anz){
              case 0: case 27:{  //reset all modes / reset inverse mode
                reverse = false;
                break;
              }
              case 7:{  //set inverse/reverse mode
                reverse = true;
                break;
              }
            }
          }
          
          escvalid = 0; 
          break;
        }          

        case 'S':{

          anz = escbuffer[esccount] > 0 ? escbuffer[esccount] : 1;
          for (r = 0; r < anz; r++){
            memset((void*)&vram[start][0], 32, WIDTH);
            start++; if (start > HEIGHT-1) start = 0;
            row++; if (row > HEIGHT-1) row = 0;
          }
          escvalid = 0;
          break;
        }
/*
        case 's':{        // save the cursor position
          saved_row = row;
          saved_col = col;
        }
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

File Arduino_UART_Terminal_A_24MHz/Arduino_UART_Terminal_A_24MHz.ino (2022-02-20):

/**************************************************************************************
  *****                                                                           *****
  ***** Atmega328P UART & PS/2 Terminal Interface written by Carsten Herting 2021 *****
  *****                   Version 2.2, last update: 02.06.2021                    *****
  *****               US-International version by Augusto Baffa Dec/21            *****
  *****                                                                           *****
  *************************************************************************************
  This Atmega328P reads serial data from it's UART RX and transfers it to the 2nd
  ATmega328P handling VGA. PS/2 data is converted into ASCII and sent away via UART TX.
  C0-C3: UART SPEED SCALER
  C4: PS/2 clock input, triggers a pin change interrupt
  C5: PS/2 dtat input, sampled at the rising edge of the PS/2 clock
  D0,1: UART RX, TX
  D2-7: bits 0-5 of transfer output to C0-5
  B0,1: bits 6-7 of transfer output to D6-7 via 1k resistors
  B2: DATA_NEW output to B0 input of 2nd µC
  See license at the end of this file.

 Fuse: FF | D9 | FF | D5

 ** Added Caps lock support jan, 6 2022 Augusto Baffa
 ** Added Num lock support jan, 8 2022 Augusto Baffa
*/
//#define DEBUG
//#define DEBUG_SCANCODE

volatile byte ps2_scan = 0;                     // holds valid PS/2 scancode (set this to 0 after processing!)

volatile bool ps2Keyboard_caps_lock = false; // remembers shift lock has been pressed
volatile bool ps2Keyboard_num_lock = false; // remembers shift lock has been pressed
volatile boolean cmd_in_progress = false;
         byte    cmd_value = 0;
volatile byte    cmd_ack_value = 1;
         byte    cmd_parity = 0;
volatile boolean cmd_ack_byte_ok = false;
volatile int     cmd_count = 0;

volatile byte    cmd_last = 0;
volatile bool    cmd_resend = false;
volatile int     cmd_resend_count = 0;

int vga_count = 0;
bool vga_show_title = true;
const char vga_title[81] PROGMEM = "\e[24;0HBaffa-Terminal v1.2\e[25;0HBased on Minimal-Terminal by Herting 2021\e[0;0H";
const char vga_clear[5] PROGMEM = "\e[2J";

const byte LookupScanToASCII[4][128] PROGMEM =  // lookup table (in: SHIFT/ALTGR/CTRL keystate and PS/2 scancode, out: ASCII code)
{ 
  { 
    // plain key
    0,120,0,116,114,112,113,123,0,121,119,117,115,9,96,0,0,0,0,0,0,113,49,0,0,0,122,115,97,119,50,0,0,99,120,100,101,52,51,0,0,32,118,102,116,114,53,0,0,110,98,104,103,121,54,0,0,0,109,106,117,55,56,0,0,44,107,105,111,48,57,0,0,46,47,108,59,112,45,0,0,0,39,0,91,61,0,0,0,0,10,93,0,92,0,0,0,92,0,0,0,0,8,0,0,0,0,0,0,46,0,0,48,127,68,53,82,85,27,78,122,43,51,45,42,0,0,0
    },
/* //OLD    
    0,0,0,0,0,0,0,0,          0,0,0,0,0,0,94,0,           0,0,0,0,0,113,49,0,         0,0,122,115,97,119,50,0,     // plain key
    0,99,120,100,101,52,51,0, 0,32,118,102,116,114,53,0,  0,110,98,104,103,121,54,0,  0,0,109,106,117,55,56,0,
    0,44,107,105,111,48,57,0, 0,46,45,108,0,112,0,0,      0,0,0,0,0,96,0,0,           0,0,10,43,0,35,0,0,
    0,60,0,0,0,0,8,0,         0,0,0,0,0,0,0,0,            0,127,0,0,0,0,27,0,         0,0,0,0,0,0,0,0          },
*/
  { 
    // with SHIFT
    0,0,0,0,0,0,0,0,0,0,0,0,0,0,126,0,0,0,0,0,0,81,33,0,0,0,90,83,65,87,64,0,0,67,88,68,69,36,35,0,0,0,86,70,84,82,37,0,0,78,66,72,71,89,94,0,0,0,77,74,85,38,42,0,0,60,75,73,79,41,40,0,0,62,63,76,58,80,95,0,0,0,34,0,123,43,0,0,0,0,0,125,0,124,0,0,0,124,0,0,0,0,0,0,0,0,0,0,0,0,0,0,0,0,0,37,0,0,0,0,0,43,35,45,42,0,0,0
    },
/* //OLD        
    0,0,0,0,0,0,0,0,          0,0,0,0,0,0,248,0,          0,0,0,0,0,81,33,0,          0,0,90,83,65,87,34,0,        // with SHIFT
    0,67,88,68,69,36,0,0,     0,0,86,70,84,82,37,0,       0,78,66,72,71,89,38,0,      0,0,77,74,85,47,40,0,
    0,59,75,73,79,61,41,0,    0,58,95,76,0,80,63,0,       0,0,0,0,0,0,0,0,            0,0,0,42,0,39,0,0,
    0,62,0,0,0,0,0,0,         0,0,0,0,0,0,0,0,            0,0,0,0,0,0,0,0,            0,0,0,0,0,0,0,0          },
*/
  { 0,0,0,0,0,0,0,0,          0,0,0,0,0,0,0,0,            0,0,0,0,0,64,0,0,           0,0,0,0,0,0,0,0,             // with ALT(GR)
    0,0,0,0,0,0,0,0,          0,0,0,0,0,0,0,0,            0,0,0,0,0,0,0,0,            0,0,0,0,0,123,91,0,
    0,0,0,0,0,125,93,0,       0,0,0,0,0,0,92,0,           0,0,0,0,0,0,0,0,            0,0,0,126,0,0,0,0,
    0,124,0,0,0,0,0,0,        0,0,0,0,0,0,0,0,            0,0,0,0,0,0,0,0,            0,0,0,0,0,0,0,0          },
  {
    // with CTRL(Strg)
    0,0,0,0,0,0,0,0,0,0,0,0,0,0,0,0,0,0,0,0,0,17,0,0,0,0,26,19,1,23,0,0,0,3,24,4,5,0,0,0,0,32,22,6,20,18,0,0,0,14,2,8,7,25,0,0,0,0,13,10,21,0,0,0,0,0,11,9,15,0,0,0,0,0,0,12,0,16,0,0,0,0,0,0,27,0,0,0,0,0,0,29,0,28,0,0,0,28,0,0,0,0,0,0,0,0,0,0,0,0,0,0,0,0,0,0,0,0,0,0,0,0,0,0,0,0,0,0
  }
};
/*    
    0,0,0,0,0,0,0,0,          0,0,0,0,0,0,0,0,            0,0,0,0,0,0x11,0,0,         0,0,0,0x13,0x01,0,0,0,             // with CTRL(Strg)
    0,0x03,0x18,0,0,0,0,0,    0,0,0x16,0,0,0,0,0,         0,0x0e,0,0,0,0x1a,0,0,      0,0,0,0,0,0,0,0,
    0,0,0,0,0,0,0,0,          0,0,0,0x0c,0,0,0,0,         0,0,0,0,0,0,0,0,            0,0,0,0,0,0,0,0,
    0,0,0,0,0,0,0,0,          0,0,0,0,0,0,0,0,            0,0,0,0,0,0,0,0,            0,0,0,0,0,0,0,0          }
};
*/
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

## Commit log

2021-12-31 . updating minimal terminal project
    [ArduinoPC.dsn, ArduinoPC.kicad_pcb, ArduinoPC.sch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]
2022-01-02 . including RC2014 terminal version . margin adjust in README.md pics . adding scan_codes.xlsx
    [minimal_terminalv2_rc2014.brd, minimal_terminalv2_rc2014.sch, scan_codes.xlsx]
2022-01-06 . Adding Charmap table (char_map.xlsx) . Fixed '^' char bitmap to VGA . Added support to Caps Lock . Fixed Clear Screen CSI Escapes
    [char_map.xlsx]
2022-01-07 . added support to inverse escape ESC[{..}m . fixed inversed ^
    [Arduino_UART_Terminal_B_24MHz.ino]
2022-01-07 . add new fonts to char_map.xlsx and some chars in fixed default font
    [char_map.xlsx]
2022-01-08 . fixed minor bugs . added support to another escapes and escape parameters separeted by semicolon
    [Arduino_UART_Terminal_B_24MHz.ino]
2022-01-08 . added splash title on start up . fixed by in \e[1J where cursor at 0,0
    [Arduino_UART_Terminal_A_24MHz.ino, Arduino_UART_Terminal_B_24MHz.ino]
2022-01-08 . fixed VGA bitmap for ` (was showing @) . fixed bug on escape \e[r;wH (screen position)
    [scan_codes.xlsx]
2022-01-08 . adding num lock support
    [scan_codes.xlsx]
2022-01-08 . updating eagle files with last fixes.
    [minimal_terminalv2.brd, minimal_terminalv2.sch, minimal_terminalv2_rc2014.brd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]
2022-01-09 . fixed ctrl \ (ibm layout keyboard with extra \ key between shift and z keys) . fixed ESC[J2 - must clear screen and set cursor position to 0,0
    [char_map.xlsx]
2022-02-20 . bit time fix in send command byte - it was causing problems with some keyboards
    [char_map.xlsx, scan_codes.xlsx]
2022-05-28 . gerbers updated . added new images
    [baffa2_minimal_terminal_rev1.GBL, baffa2_minimal_terminal_rev1.GBO, baffa2_minimal_terminal_rev1.GBP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]
2022-05-28 . adding schematics
2022-07-28 . adding apple 1 and apple ][ charmap
    [char_map.xlsx]
2022-07-29 adding prototype ugly pics :D

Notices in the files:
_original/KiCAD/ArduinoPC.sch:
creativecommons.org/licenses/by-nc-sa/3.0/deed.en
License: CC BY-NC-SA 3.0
